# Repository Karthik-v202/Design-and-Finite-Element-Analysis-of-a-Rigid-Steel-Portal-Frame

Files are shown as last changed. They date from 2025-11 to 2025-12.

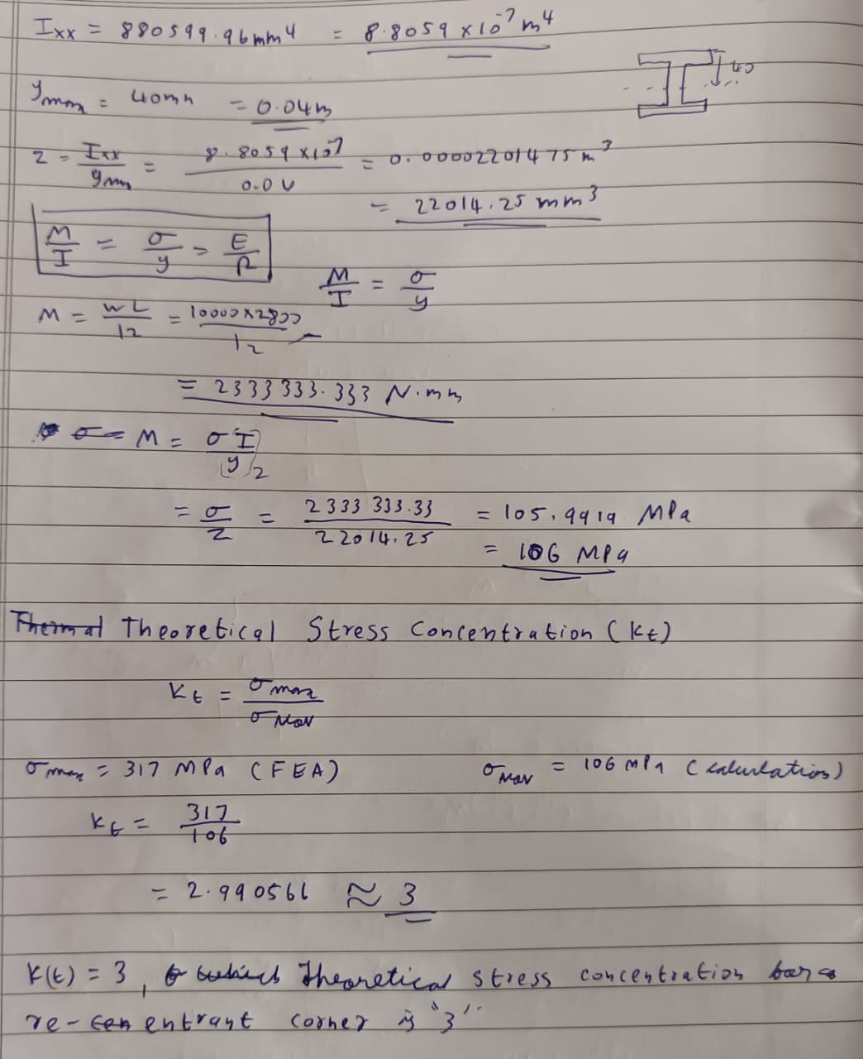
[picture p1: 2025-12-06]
Assets/WhatsApp Image 2025-12-06 at 09.29.01_5a571347.jpg

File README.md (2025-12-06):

# Design and Finite Element Analysis of a Rigid Steel Portal Frame 🏗️

Project Banner
*An industry-standard portal frame designed in SolidWorks, featuring moment-resisting connections and optimized load paths.*

## 🛠️ Tech Stack





## 📖 Project Overview
This project involves the design, failure analysis, and optimization of a structural steel portal frame intended for an industrial warehouse.

Moving beyond basic geometric modeling, this project applies the Six Sigma DMAIC methodology to troubleshoot initial simulation failures (rigid body motion & singularities) and optimize the design to withstand a roof load of $10 \text{ kN}$. The analysis focuses on critical stress concentrations at the eave connections and ensures the structural integrity of the frame through rigorous Finite Element Analysis (FEA).

## ⚙️ Key Design Features (The "Why")

### 1. Haunched Eaves Connection
Haunch Detail
* **Problem:** The connection between the column and rafter experiences the highest **Bending Moment** in the entire structure.
* **Solution:** Designed a tapered haunch to increase the beam depth at the joint. This significantly reduces stress concentration and allows for a lighter rafter section elsewhere.

### 2. Internal Column Stiffeners (Continuity Plates)
Stiffener Detail
* **Problem:** The compression force from the haunch flange pushes directly against the column web, creating a risk of **Local Web Buckling**.
* **Solution:** Modeled horizontal continuity plates inside the column to bridge the load path and transfer forces effectively.

### 3. Detailed Bolted Assemblies
* Utilized standard structural bolts with appropriate pre-tension clusters in the tension zones.
* Designed flush end-plates for manufacturability.

## 🧪 Simulation & Analysis (FEA)
🚩 The Challenge (Define & Measure)

Initial simulations using Beam Elements failed due to connectivity errors (resulting in "flying parts"). Subsequent runs utilizing Solid Elements revealed a peak stress of $475 \text{ MPa}$ at the re-entrant corners. This was identified as a Singularity, which exceeded the yield strength of the initial material (ASTM A36, $S_y=250 \text{ MPa}$).

🛠️ The Fix (Analyze & Improve)

To resolve these issues, the design underwent a rigorous optimization process:

Geometry: Converted all members to Solid Bodies to enable accurate face-to-face bonding and contact set definition.

Refinement: Added Fillet Radii ($5 \text{ mm}$) to simulate weld beads. This smoothed stress flow trajectories and eliminated mathematical singularities caused by sharp corners.

Material Upgrade: Upgraded the material specification from ASTM A36 ($S_y=250 \text{ MPa}$) to ASTM A992 ($S_y=345 \text{ MPa}$) to handle higher allowable stresses.

📸 Final Results (Control)

Stress Final
Stress Almost
Stress Fail

| Metric | Initial Design (Fail) | Optimized Design (Pass) |
| :--- | :--- | :--- |
| **Material** | ASTM A36 ($S_y=250 \text{ MPa}$) | **ASTM A992 (**$S_y=345 \text{ MPa}$**)** |
| **Peak Stress** | $475 \text{ MPa}$ (Singularity) | $317 \text{ MPa}$ **(Safe)** |
| **Deflection** | Infinite (Error) | $5.12 \text{ mm}$ **(Rigid)** |
| **Stability (BLF)** | N/A | $5.05$ **(Extremely Stable)** |

📐 Theoretical Validation

The FEA results were verified against manual Beam Theory calculations to ensure accuracy:

Static Equilibrium: Confirmed $\sum F_y = 0$.

Stress Check: Hand calculations predicted a nominal stress of $106 \text{ MPa}$. The FEA peak of $317 \text{ MPa}$ yields a ratio of $\approx 3.3$. This correlates accurately with the theoretical Stress Concentration Factor ($K_t$) expected for sharp corners and welded joints.

Stiffness Check: The FEA deflection ($5.12 \text{ mm}$) aligns closely with the Fixed-Fixed beam approximation calculation ($3.24 \text{ mm}$), confirming the rigid behavior of the connections.

## 📂 File Structure
- `CAD_Files/`: Native SolidWorks 2024 files.
- `Universal_Formats/`: STEP files for non-SW users.
- `Simulation_Reports/` : Comprehensive report.
- `Drawings/`: 2D Fabrication prints (PDF).

## 👨‍💻 Author
**Karthik V S**
Mechanical Engineering Undergraduate
https://www.linkedin.com/in/karthik-v-s-926b34335

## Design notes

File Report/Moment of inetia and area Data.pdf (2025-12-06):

Measurements are based on sectioned model Section properties of the selected face of steel

Area = 783.24 millimeters^2

Centroid relative to assembly origin: ( millimeters ) X = 0.00
Y = 1995.44
Z = 2204.47

Moments of inertia of the area, at the centroid: ( millimeters ^ 4 )
Lxx = 880599.96 | Lxy = 0.00Lxz = 0.00
Lyx = 0.00 Lyy = 56615.33 | Lyz = 0.01
Lzx = 0.00Lzy = 0.01Lzz = 823984.63

Polar moment of inertia of the area, at the centroid = 880599.96 millimeters ^ 4

Angle between principal axes and assembly coordinate axes = -0.00 degrees

Principal moments of inertia of the area, at the centroid: ( millimeters ^ 4 )
Ix = 56615.33
Iy = 823984.63

Moments of inertia of the area, at the output coordinate system: ( millimeters ^ 4 )
LXX = 6925889576.18 | LXY = 0.00 | LXZ = 0.00
LYX = 0.00 LYY = 3806356861.54LYZ = 3445394289.02
LZX = 0.00 | LZY = 3445394289.02 | LZZ = 3119532714.64

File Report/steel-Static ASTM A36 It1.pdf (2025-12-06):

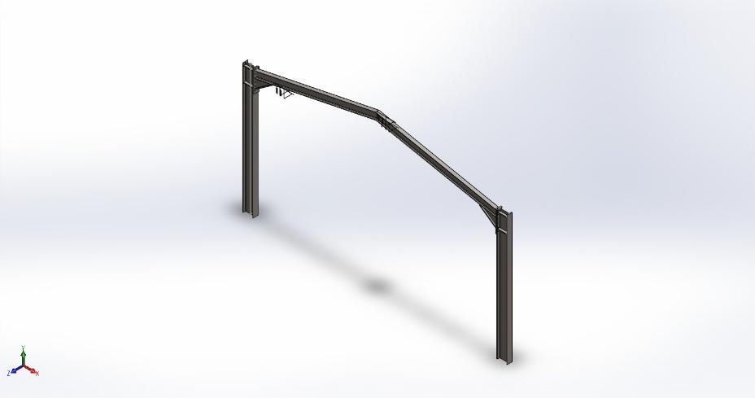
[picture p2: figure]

Analyzed with SOLIDWORKS Simulation | Simulation of steel | 1

# Simulation of steel

Date: 01 December 2025
Designer: Solidworks
Study name: Static 1
Analysis type: Static

## Table of Contents

## Description

No Data

## Assumptions

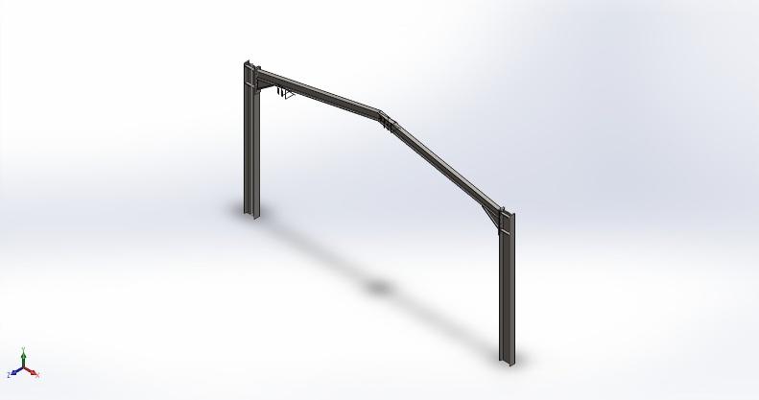
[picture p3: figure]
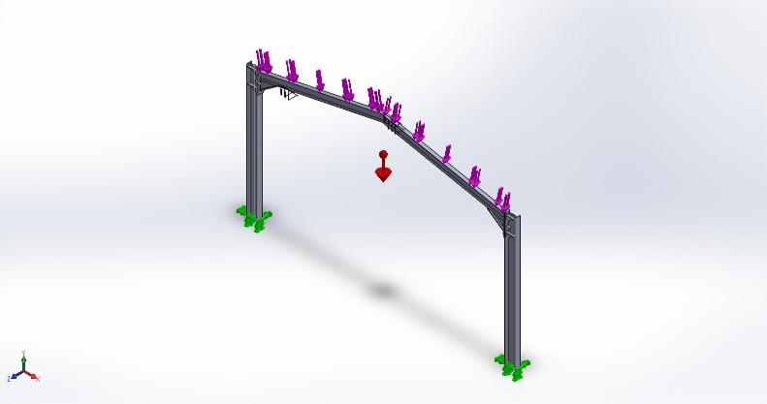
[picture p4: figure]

Original Model | Model Analyzed

## Model Information

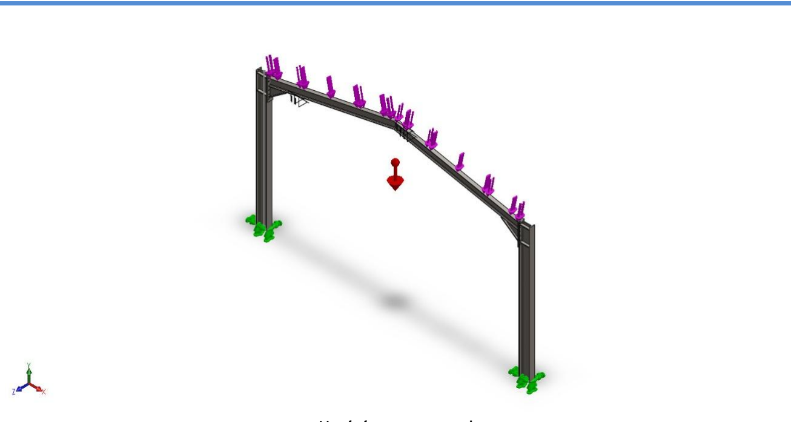
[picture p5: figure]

Model name: steel
Current Configuration: Default

### Solid Bodies

Document Name and Reference | Treated As | Volumetric Properties | Document Path/Date Modified
Trim/Extend1[1] | Solid Body | Mass:8.65652 kg Volume:0.00110274 m^3 Density:7,850 kg/m^3 Weight:84.8339 N | C:\Users\HP\Desktop\CAD _Files\Steel 1.SLDPRT Dec 1 16:14:57 2025
Mirror2[1] | Solid Body | Mass:0.615448 kg Volume:7.8401e-05 m^3 Density:7,850 kg/m^3 Weight:6.03139 N | C:\Users\HP\Desktop\CAD _Files\Steel 1.SLDPRT Dec 1 16:14:57 2025

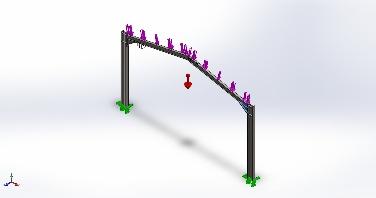
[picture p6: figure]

Cut-Extrude3[1] | Solid Body | Mass:17.1355 kg Volume:0.00218286 m^3 Density:7,850 kg/m^3 Weight:167.928 N | C:\Users\HP\Desktop\CAD _Files\Steel 1.SLDPRT Dec 1 16:14:57 2025

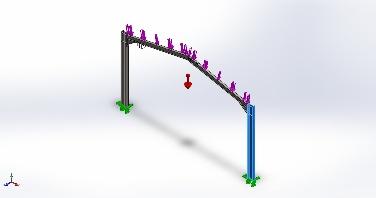
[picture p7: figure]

Gusset1 | Solid Body | Mass:0.615448 kg Volume:7.8401e-05 m^3 Density:7,850 kg/m^3 Weight:6.03139 N | C:\Users\HP\Desktop\CAD _Files\Steel 1.SLDPRT Dec 1 16:14:57 2025

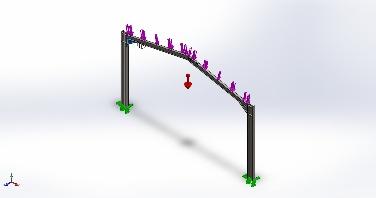
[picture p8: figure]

Trim/Extend1[2] | Solid Body | Mass:8.65652 kg Volume:0.00110274 m^3 Density:7,850 kg/m^3 Weight:84.8339 N | C:\Users\HP\Desktop\CAD _Files\Steel 1.SLDPRT Dec 1 16:14:57 2025
Cut-Extrude2[1] | Solid Body | Mass:17.1584 kg Volume:0.00218578 m^3 Density:7,850 kg/m^3 Weight:168.152 N | C:\Users\HP\Desktop\CAD _Files\Steel 1.SLDPRT Dec 1 16:14:57 2025

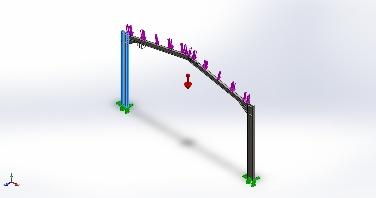
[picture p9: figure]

## Study Properties

Study name | Static 1
Analysis type | Static
Mesh type | Mixed Mesh
Thermal Effect: | On
Thermal option | Include temperature loads
Zero strain temperature | 298 Kelvin
Include fluid pressure effects from SOLIDWORKS Flow Simulation | Off
Solver type | Automatic
Inplane Effect: | Off
Soft Spring: | Off
Inertial Relief: | Off
Incompatible bonding options | Automatic
Large displacement | Off
Compute free body forces | On
Friction | Off
Use Adaptive Method: | Off
Result folder | SOLIDWORKS document (C:\Users\HP\Desktop\CAD_Files)

## Units

Unit system: | SI (MKS)
Length/Displacement | mm
Temperature | Kelvin
Angular velocity | Rad/sec
Pressure/Stress | N/m^2

## Material Properties

Model Reference | Properties | Components
| Name: ASTM A36 Steel Model type: Linear Elastic Isotropic Default failure criterion: Max von Mises Stress
| Yield strength: 2.5e+08 N/m^2 Tensile strength: 4e+08 N/m^2 Elastic modulus: 2e+11 N/m^2 Poisson's ratio: 0.26 Mass density: 7,850 kg/m^3 Shear modulus: 7.93e+10 N/m^2

SolidBody 1(Base-Flange14)(Steel 1-2),
SolidBody 2(Base-Flange2)(Steel 1-2),
SolidBody 3(Base-Flange9)(Steel 1-2),
SolidBody 4(Base-Flange13)(Steel 1-2),
SolidBody
5(Trim/Extend1[1])(Steel 1-2),
SolidBody 6(Cut-Extrude2[2])(Steel 1-2),
SolidBody 7(Base-Flange4)(Steel 1-2),
SolidBody 8(Base-Flange8)(Steel 1-2),
SolidBody 9(Base-Flange12)(Steel 1-2),
SolidBody
10(Mirror2[1])(Steel 1-2), SolidBody 11(Cut-Extrude3[1])(Steel 1-2),
SolidBody 12(Base-Flange7)(Steel 1-2),
SolidBody 13(Base-Flange11)(Steel 1-2),
SolidBody 14(Gusset1)(Steel 1-2),
SolidBody
15(Trim/Extend1[2])(Steel 1-2),
SolidBody 16(Cut-Extrude2[1])(Steel 1-2),
SolidBody 17(Cut-Extrude3[2])(Steel 1-2),
SolidBody 18(Base-Flange10)(Steel 1-2)

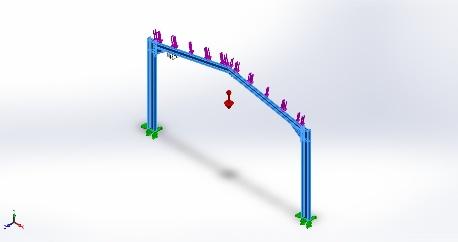
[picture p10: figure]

Curve Data:N/A

## Loads and Fixtures

Fixture name | Fixture Image | Fixture Details

Fixed-1

Entities: 2 face(s)
Type: Fixed
Geometry

Resultant Forces

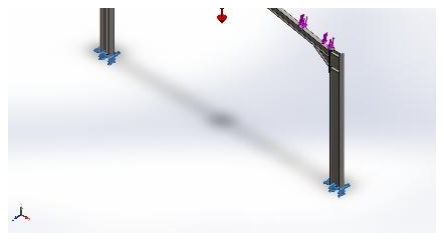
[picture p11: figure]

Components | X | Y | Z | Resultant
Reaction force(N) | -0.0880032 | 20,168.1 | 0.140892 | 20,168.1
Reaction Moment(N.m) | 0 | 0 | 0 | 1e-33
Load name | Load Image | Load Details

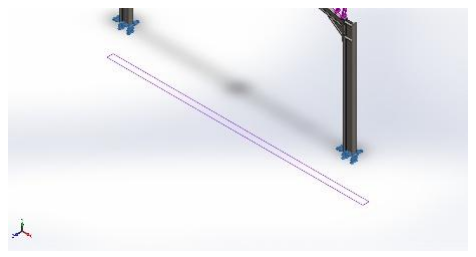
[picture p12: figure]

Gravity-1

Reference: Top Plane
Values: 0 0 -9.81
Units: m/s^2

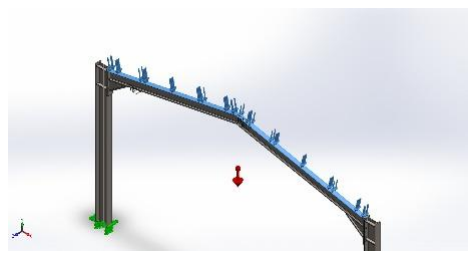
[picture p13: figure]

Force-1

Entities: 2 face(s)
Type: Apply
normal
force
Value: 10,000 N

## Connector Definitions

No Data

## Interaction Information

Interaction | Interaction Image | Interaction Properties

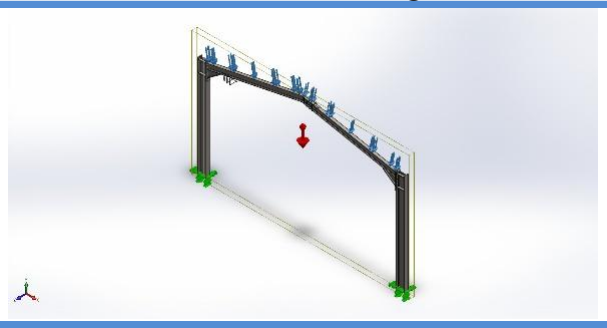
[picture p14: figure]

Global Interaction | | Type: Bonded Components: 1 component(s) Options: Independent mesh

## Mesh information

Mesh type | Mixed Mesh
Mesher Used: | Blended curvature-based mesh
Jacobian points for High quality mesh | 16 Points
Jacobian check for shell | On
Maximum element size | 30.3492 mm
Minimum element size | 1.51746 mm
Mesh Quality | High
Remesh failed parts independently | Off
Reuse mesh for identical parts in an assembly (Blended curvature-based mesher only) | Off

### Mesh information - Details

Total Nodes | 682917
Total Elements | 374468
Time to complete mesh(hh;mm;ss): | 00:00:31

Computer name:

### Mesh Quality Plots

Name | Type | Min | Max
Quality1 | Mesh | - | -

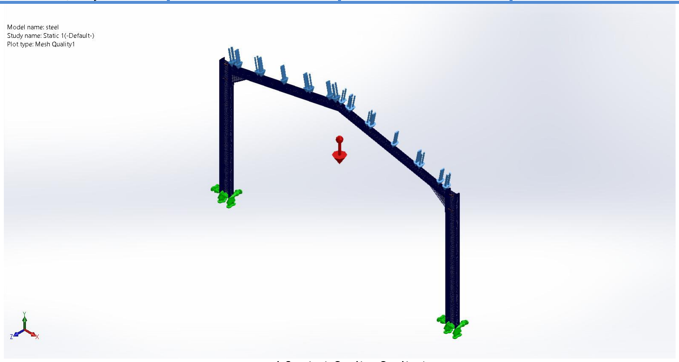
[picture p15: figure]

steel-Static 1-Quality-Quality1

## Sensor Details

No Data

## Resultant Forces

### Reaction forces

Selection set | Units | Sum X | Sum Y | Sum Z | Resultant
Entire Model | N | -0.0880032 | 20,168.1 | 0.140892 | 20,168.1

### Reaction Moments

Selection set | Units | Sum X | Sum Y | Sum Z | Resultant
Entire Model | N.m | 0 | 0 | 0 | 1e-33

### Free body forces

Selection set | Units | Sum X | Sum Y | Sum Z | Resultant
Entire Model | N | -5.40119 | 402.134 | -33.7607 | 403.585

### Free body moments

Selection set | Units | Sum X | Sum Y | Sum Z | Resultant
Entire Model | N.m | -0.307049 | -0.0124856 | 0.213525 | 0.374203

## Beams

### No Data

## Study Results

Name | Type | Min | Max
Stress1 | VON: von Mises Stress | 1.079e+04N/m^2 Node: 302349 | 4.749e+08N/m^2 Node: 526510

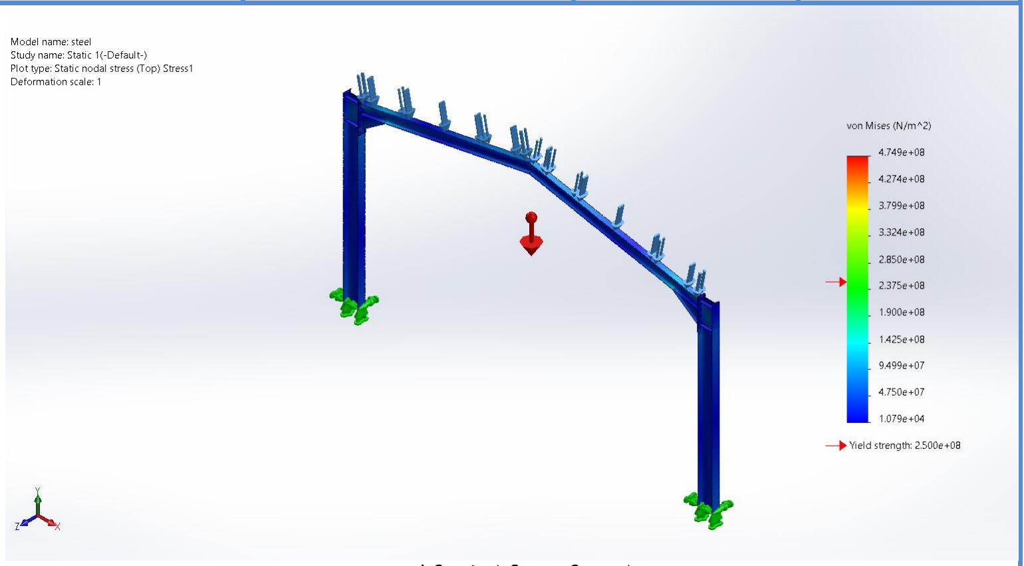
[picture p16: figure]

steel-Static 1-Stress-Stress1

Name | Type | Min | Max
Displacement1 | URES: Resultant Displacement | 0.000e+00mm Node: 191339 | 5.124e+00mm Node: 6452

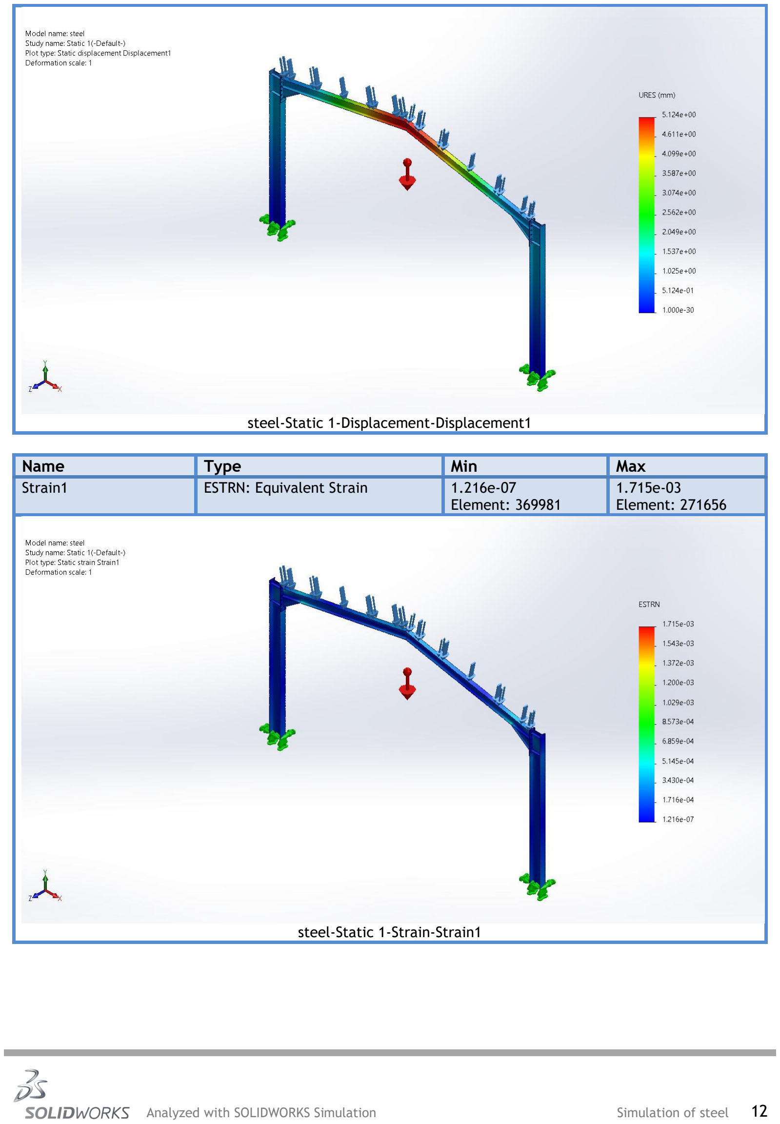
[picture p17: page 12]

steel-Static 1-Displacement-Displacement1

Name | Type | Min | Max
Strain1 | ESTRN: Equivalent Strain | 1.216e-07 Element: 369981 | 1.715e-03 Element: 271656

steel-Static 1-Strain-Strain1

## Conclusion

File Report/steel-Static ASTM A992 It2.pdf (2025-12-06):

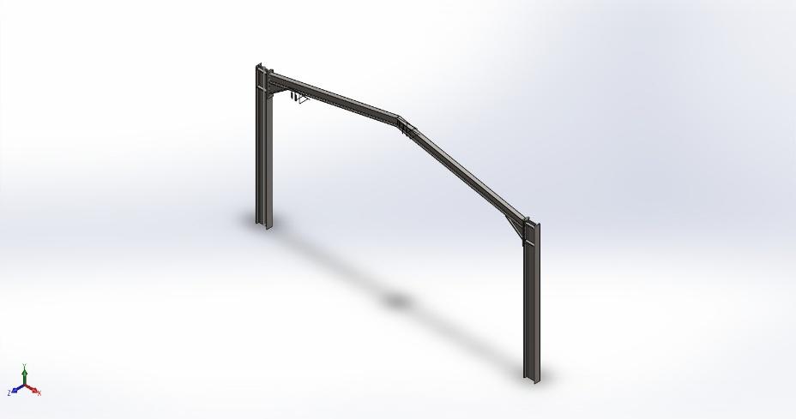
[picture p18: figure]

Analyzed with SOLIDWORKS Simulation | Simulation of steel | 1

# Simulation of steel

Date: 01 December 2025
Designer: Solidworks
Study name: Static 2
Analysis type: Static

## Table of Contents

## Description

No Data

## Assumptions

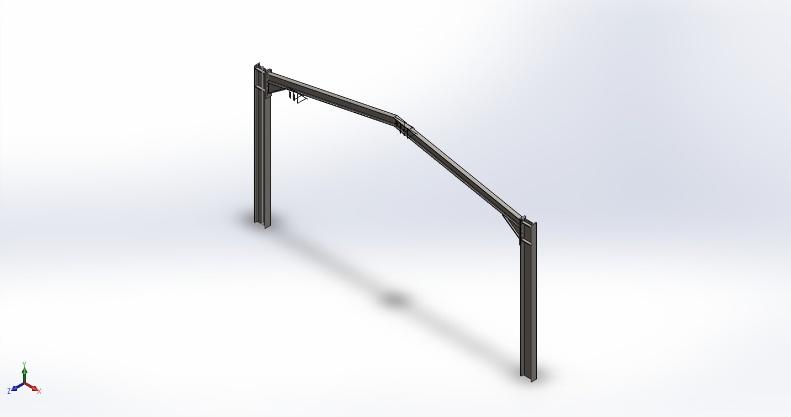
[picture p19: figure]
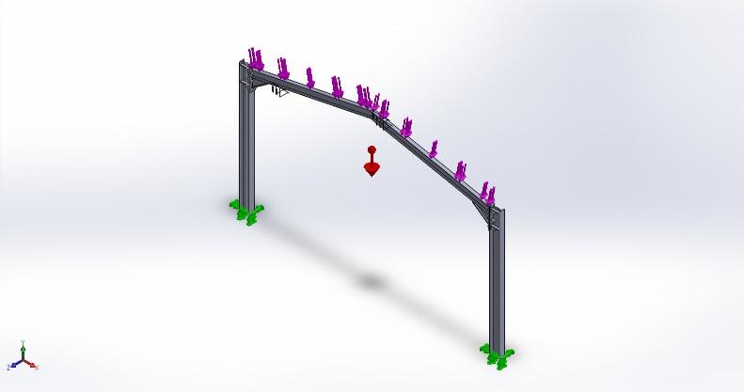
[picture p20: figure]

Original Model | Model Analyzed

## Model Information


Model name: steel
Current Configuration: Default

### Solid Bodies

Document Name and Reference | Treated As | Volumetric Properties | Document Path/Date Modified
Trim/Extend1[2] | Solid Body | Mass:8.65652 kg Volume:0.00110274 m^3 Density:7,850 kg/m^3 Weight:84.8339 N | C:\Users\HP\Desktop\CAD _Files\Steel 1.SLDPRT Dec 1 16:14:57 2025
Mirror2[1] | Solid Body | Mass:0.615448 kg Volume:7.8401e-05 m^3 Density:7,850 kg/m^3 Weight:6.03139 N | C:\Users\HP\Desktop\CAD _Files\Steel 1.SLDPRT Dec 1 16:14:57 2025


Cut-Extrude3[1] | Solid Body | Mass:17.1355 kg Volume:0.00218286 m^3 Density:7,850 kg/m^3 Weight:167.928 N | C:\Users\HP\Desktop\CAD _Files\Steel 1.SLDPRT Dec 1 16:14:57 2025


Gusset1 | Solid Body | Mass:0.615448 kg Volume:7.8401e-05 m^3 Density:7,850 kg/m^3 Weight:6.03139 N | C:\Users\HP\Desktop\CAD _Files\Steel 1.SLDPRT Dec 1 16:14:57 2025


Trim/Extend1[1] | Solid Body | Mass:8.65652 kg Volume:0.00110274 m^3 Density:7,850 kg/m^3 Weight:84.8339 N | C:\Users\HP\Desktop\CAD _Files\Steel 1.SLDPRT Dec 1 16:14:57 2025
Cut-Extrude2[1] | Solid Body | Mass:17.1584 kg Volume:0.00218578 m^3 Density:7,850 kg/m^3 Weight:168.152 N | C:\Users\HP\Desktop\CAD _Files\Steel 1.SLDPRT Dec 1 16:14:57 2025


## Study Properties

Study name | Static 2
Analysis type | Static
Mesh type | Mixed Mesh
Thermal Effect: | On
Thermal option | Include temperature loads
Zero strain temperature | 298 Kelvin
Include fluid pressure effects from SOLIDWORKS Flow Simulation | Off
Solver type | Automatic
Inplane Effect: | Off
Soft Spring: | Off
Inertial Relief: | Off
Incompatible bonding options | Automatic
Large displacement | Off
Compute free body forces | On
Friction | Off
Use Adaptive Method: | Off
Result folder | SOLIDWORKS document (C:\Users\HP\Desktop\CAD_Files)

## Units

Unit system: | SI (MKS)
Length/Displacement | mm
Temperature | Kelvin
Angular velocity | Rad/sec
Pressure/Stress | N/m^2

## Material Properties

Model Reference | Properties | Components
| Name: ASTM A992 Model type: Linear Elastic Isotropic Default failure criterion: Max von Mises Stress
| Yield strength: 3.45e+08 N/m^2 Tensile strength: 4e+08 N/m^2 Elastic modulus: 2e+11 N/m^2 Poisson's ratio: 0.26 Mass density: 7,850 kg/m^3 Shear modulus: 7.93e+10 N/m^2

SolidBody
1(Trim/Extend1[2])(Steel 1-2),
SolidBody 2(Mirror2[1])(Steel 1-2),
SolidBody 3(Cut-Extrude3[2])(Steel 1-2),
SolidBody 4(Cut-Extrude3[1])(Steel 1-2),
SolidBody 5(Base-Flange13)(Steel 1-2),
SolidBody 6(Base-Flange11)(Steel 1-2),
SolidBody 7(Base-Flange9)(Steel 1-2),
SolidBody 8(Base-Flange7)(Steel 1-2),
SolidBody 9(Gusset1)(Steel 1-2),
SolidBody
10(Trim/Extend1[1])(Steel 1-2),
SolidBody 11(Cut-Extrude2[2])(Steel 1-2),
SolidBody 12(Base-Flange12)(Steel 1-2),
SolidBody 13(Base-Flange2)(Steel 1-2),
SolidBody 14(Cut-Extrude2[1])(Steel 1-2),
SolidBody 15(Base-Flange10)(Steel 1-2),
SolidBody 16(Base-Flange4)(Steel 1-2),
SolidBody 17(Base-Flange8)(Steel 1-2),
SolidBody 18(Base-Flange14)(Steel 1-2)

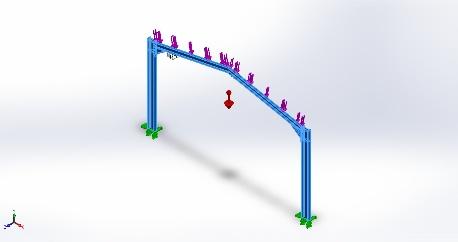
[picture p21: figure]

Curve Data:N/A

## Loads and Fixtures

Fixture name | Fixture Image | Fixture Details

Fixed-1

Entities: 2 face(s)
Type: Fixed
Geometry

Resultant Forces


Components | X | Y | Z | Resultant
Reaction force(N) | -0.122177 | 20,167.2 | -0.103241 | 20,167.2
Reaction Moment(N.m) | 0 | 0 | 0 | 1e-33
Load name | Load Image | Load Details


Gravity-1

Reference: Top Plane
Values: 0 0 -9.81
Units: m/s^2

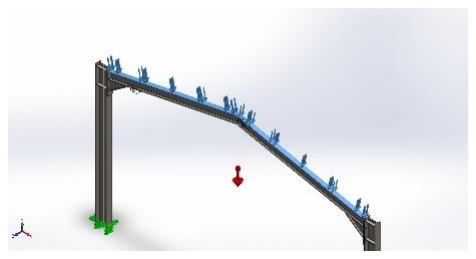
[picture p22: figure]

Force-1

Entities: 2 face(s)
Type: Apply
normal
force
Value: 10,000 N

## Connector Definitions

No Data

## Interaction Information

Interaction | Interaction Image | Interaction Properties


Global Interaction | | Type: Bonded Components: 1 component(s) Options: Independent mesh

## Mesh information

Mesh type | Mixed Mesh
Mesher Used: | Blended curvature-based mesh
Jacobian points for High quality mesh | 16 Points
Jacobian check for shell | On
Maximum element size | 30.3492 mm
Minimum element size | 1.51746 mm
Mesh Quality | High
Remesh failed parts independently | Off
Reuse mesh for identical parts in an assembly (Blended curvature-based mesher only) | Off

### Mesh information - Details

Total Nodes | 682917
Total Elements | 374468
Time to complete mesh(hh;mm;ss): | 00:00:54

Computer name:

### Mesh Quality Plots

Name | Type | Min | Max
Quality1 | Mesh | - | -

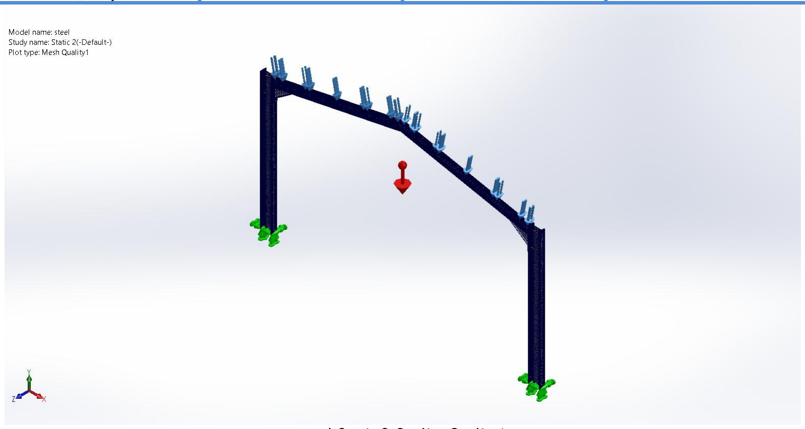
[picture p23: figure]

steel-Static 2-Quality-Quality1

## Sensor Details

No Data

## Resultant Forces

### Reaction forces

Selection set | Units | Sum X | Sum Y | Sum Z | Resultant
Entire Model | N | -0.122177 | 20,167.2 | -0.103241 | 20,167.2

### Reaction Moments

Selection set | Units | Sum X | Sum Y | Sum Z | Resultant
Entire Model | N.m | 0 | 0 | 0 | 1e-33

### Free body forces

Selection set | Units | Sum X | Sum Y | Sum Z | Resultant
Entire Model | N | -6.93514 | 387.366 | 48.4837 | 390.45

### Free body moments

Selection set | Units | Sum X | Sum Y | Sum Z | Resultant
Entire Model | N.m | -0.332162 | -0.0124793 | 0.190236 | 0.382985

## Beams

### No Data

## Study Results

Name | Type | Min | Max
Stress1 | VON: von Mises Stress | 1.208e+04N/m^2 Node: 530277 | 4.749e+08N/m^2 Node: 187743

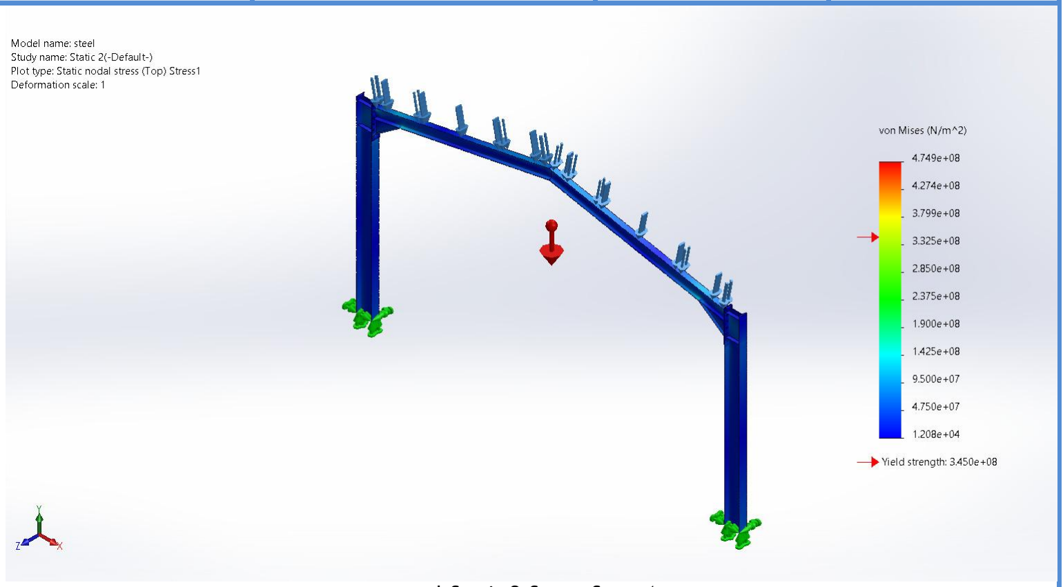
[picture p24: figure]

steel-Static 2-Stress-Stress1

Name | Type | Min | Max
Displacement1 | URES: Resultant Displacement | 0.000e+00mm Node: 191708 | 5.124e+00mm Node: 6460

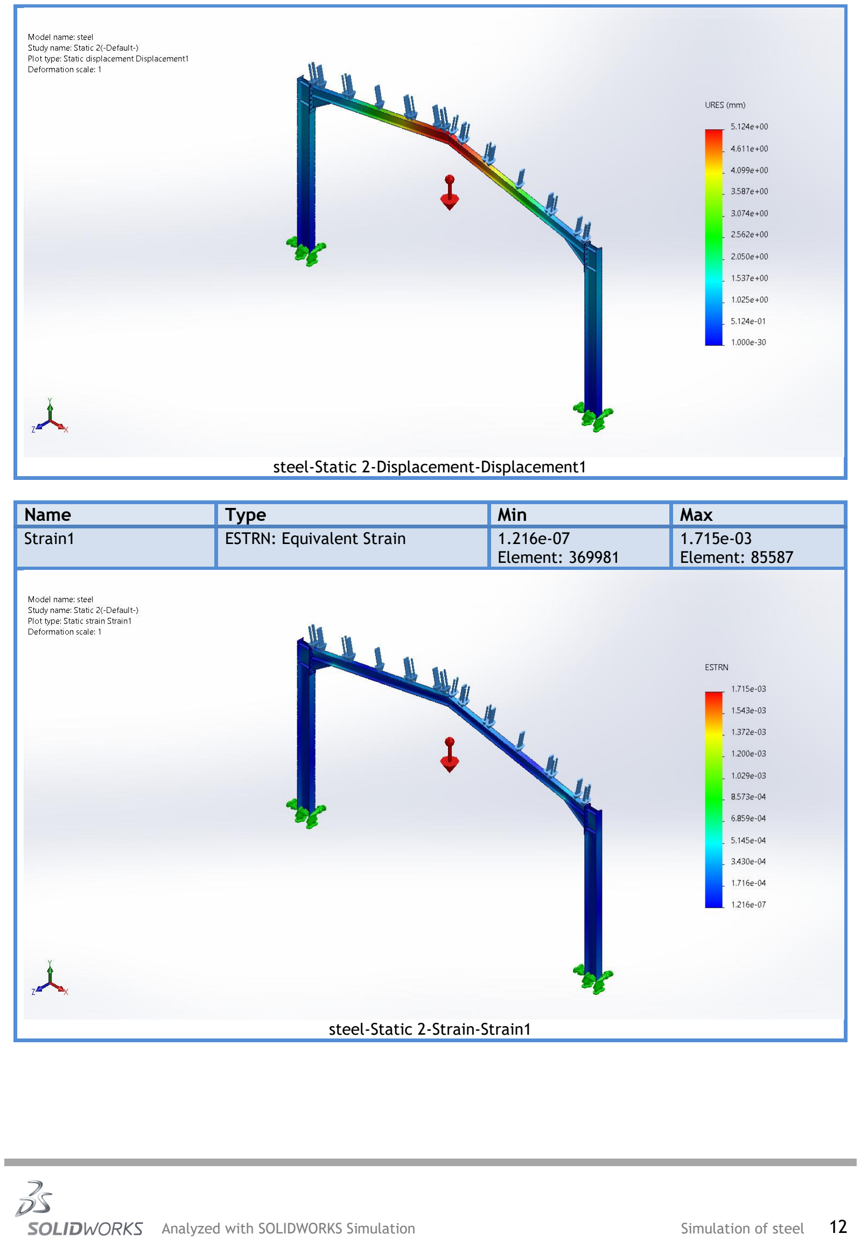
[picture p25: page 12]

steel-Static 2-Displacement-Displacement1

Name | Type | Min | Max
Strain1 | ESTRN: Equivalent Strain | 1.216e-07 Element: 369981 | 1.715e-03 Element: 85587

steel-Static 2-Strain-Strain1

## Conclusion

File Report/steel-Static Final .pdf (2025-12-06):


Analyzed with SOLIDWORKS Simulation | Simulation of steel | 1

# Simulation of steel

Date: 05 December 2025
Designer: Karthik V S
Study name: Static 1
Analysis type: Static

## Table of Contents

## Description

No Data

Karthik V S
05-12-2025

## Assumptions


Original Model | Model Analyzed

## Model Information


Model name: steel
Current Configuration: Default

### Solid Bodies

Document Name and Reference | Treated As | Volumetric Properties | Document Path/Date Modified
Fillet Bead15 | Solid Body | Mass:0.0286001 kg Volume:3.64333e-06 m^3 Density:7,850 kg/m^3 Weight:0.280281 N | C:\Users\HP\Desktop\Test cad\Steel 1.SLDPRT Dec 1 22:43:37 2025


Base-Flange10 | Solid Body | Mass:0.156986 kg Volume:1.99983e-05 m^3 Density:7,850 kg/m^3 Weight:1.53847 N | C:\Users\HP\Desktop\Test cad\Steel 1.SLDPRT Dec 1 22:43:37 2025
Fillet Bead24 | Solid Body | Mass:0.0231394 kg Volume:2.94769e-06 m^3 Density:7,850 kg/m^3 Weight:0.226766 N | C:\Users\HP\Desktop\Test cad\Steel 1.SLDPRT Dec 1 22:43:37 2025


Base-Flange7 | Solid Body | Mass:0.156986 kg Volume:1.99983e-05 m^3 Density:7,850 kg/m^3 Weight:1.53847 N | C:\Users\HP\Desktop\Test cad\Steel 1.SLDPRT Dec 1 22:43:37 2025


Fillet Bead22 | Solid Body | Mass:0.0286001 kg Volume:3.64333e-06 m^3 Density:7,850 kg/m^3 | C:\Users\HP\Desktop\Test cad\Steel 1.SLDPRT Dec 1 22:43:37 2025

Weight:0.280281 N

Fillet18 | Solid Body | Mass:9.90897 kg Volume:0.00126229 m^3 Density:7,850 kg/m^3 Weight:97.1079 N | C:\Users\HP\Desktop\Test cad\Steel 1.SLDPRT Dec 1 22:43:37 2025


Base-Flange11 | Solid Body | Mass:0.156986 kg Volume:1.99983e-05 m^3 Density:7,850 kg/m^3 Weight:1.53847 N | C:\Users\HP\Desktop\Test cad\Steel 1.SLDPRT Dec 1 22:43:37 2025


Cut-Extrude2[1] | Solid Body | Mass:17.1584 kg Volume:0.00218578 m^3 Density:7,850 kg/m^3 Weight:168.152 N | C:\Users\HP\Desktop\Test cad\Steel 1.SLDPRT Dec 1 22:43:37 2025


Cut-Extrude3[1] | Solid Body | Mass:17.1355 kg Volume:0.00218286 m^3 Density:7,850 kg/m^3 Weight:167.928 N | C:\Users\HP\Desktop\Test cad\Steel 1.SLDPRT Dec 1 22:43:37 2025
Base-Flange8 | Solid Body | Mass:0.156986 kg Volume:1.99983e-05 m^3 Density:7,850 kg/m^3 Weight:1.53847 N | C:\Users\HP\Desktop\Test cad\Steel 1.SLDPRT Dec 1 22:43:37 2025


Base-Flange14 | Solid Body | Mass:0.156986 kg Volume:1.99983e-05 m^3 Density:7,850 kg/m^3 Weight:1.53847 N | C:\Users\HP\Desktop\Test cad\Steel 1.SLDPRT Dec 1 22:43:37 2025


Fillet Bead10 | Solid Body | Mass:0.0286001 kg Volume:3.64333e-06 m^3 Density:7,850 kg/m^3 Weight:0.280281 N | C:\Users\HP\Desktop\Test cad\Steel 1.SLDPRT Dec 1 22:43:37 2025
Fillet Bead17 | Solid Body | Mass:0.0231394 kg Volume:2.94769e-06 m^3 | C:\Users\HP\Desktop\Test cad\Steel 1.SLDPRT

Density:7,850 kg/m^3 Weight:0.226766 N | Dec 1 22:43:37 2025


Gusset1 | Solid Body | Mass:0.615448 kg Volume:7.8401e-05 m^3 Density:7,850 kg/m^3 Weight:6.03139 N | C:\Users\HP\Desktop\Test cad\Steel 1.SLDPRT Dec 1 22:43:37 2025


Mirror2[1] | Solid Body | Mass:0.615448 kg Volume:7.8401e-05 m^3 Density:7,850 kg/m^3 Weight:6.03139 N | C:\Users\HP\Desktop\Test cad\Steel 1.SLDPRT Dec 1 22:43:37 2025


Fillet Bead16 | Solid Body | Mass:0.0231394 kg Volume:2.94769e-06 m^3 Density:7,850 kg/m^3 Weight:0.226766 N | C:\Users\HP\Desktop\Test cad\Steel 1.SLDPRT Dec 1 22:43:37 2025
Base-Flange12 | Solid Body | Mass:0.156986 kg Volume:1.99983e-05 m^3 Density:7,850 kg/m^3 Weight:1.53847 N | C:\Users\HP\Desktop\Test cad\Steel 1.SLDPRT Dec 1 22:43:37 2025


Base-Flange2 | Solid Body | Mass:0.604748 kg Volume:7.7038e-05 m^3 Density:7,850 kg/m^3 Weight:5.92653 N | C:\Users\HP\Desktop\Test cad\Steel 1.SLDPRT Dec 1 22:43:37 2025


Base-Flange9 | Solid Body | Mass:0.156986 kg Volume:1.99983e-05 m^3 Density:7,850 kg/m^3 Weight:1.53847 N | C:\Users\HP\Desktop\Test cad\Steel 1.SLDPRT Dec 1 22:43:37 2025


Fillet13 | Solid Body | Mass:9.9117 kg Volume:0.00126264 m^3 Density:7,850 kg/m^3 Weight:97.1347 N | C:\Users\HP\Desktop\Test cad\Steel 1.SLDPRT Dec 1 22:43:37 2025
Base-Flange4 | Solid Body | Mass:0.604748 kg Volume:7.7038e-05 m^3 | C:\Users\HP\Desktop\Test cad\Steel 1.SLDPRT

Density:7,850 kg/m^3 Weight:5.92653 N | Dec 1 22:43:37 2025


Base-Flange13 | Solid Body | Mass:0.156986 kg Volume:1.99983e-05 m^3 Density:7,850 kg/m^3 Weight:1.53847 N | C:\Users\HP\Desktop\Test cad\Steel 1.SLDPRT Dec 1 22:43:37 2025


Fillet Bead18 | Solid Body | Mass:0.0286001 kg Volume:3.64333e-06 m^3 Density:7,850 kg/m^3 Weight:0.280281 N | C:\Users\HP\Desktop\Test cad\Steel 1.SLDPRT Dec 1 22:43:37 2025

## Study Properties

Study name | Static 1
Analysis type | Static
Mesh type | Solid Mesh
Thermal Effect: | On
Thermal option | Include temperature loads
Zero strain temperature | 298 Kelvin
Include fluid pressure effects from SOLIDWORKS Flow Simulation | Off
Solver type | Automatic
Inplane Effect: | Off
Soft Spring: | Off
Inertial Relief: | Off
Incompatible bonding options | Automatic
Large displacement | Off
Compute free body forces | On
Friction | Off
Use Adaptive Method: | Off
Result folder | SOLIDWORKS document (C:\Users\HP\Desktop\Test cad)

## Units

Unit system: | SI (MKS)
Length/Displacement | mm
Temperature | Kelvin
Angular velocity | Rad/sec
Pressure/Stress | N/m^2

## Material Properties

Model Reference | Properties | Components
| Name: ASTM A992 Model type: Linear Elastic Isotropic Default failure criterion: Max von Mises Stress
| Yield strength: 3.45e+08 N/m^2 Tensile strength: 4e+08 N/m^2 Elastic modulus: 2e+11 N/m^2 Poisson's ratio: 0.26 Mass density: 7,850 kg/m^3 Shear modulus: 7.93e+10 N/m^2

SolidBody 1(Fillet
Bead15)(Steel 1-2),
SolidBody 2(Base-Flange10)(Steel 1-2),
SolidBody 3(Fillet
Bead24)(Steel 1-2),
SolidBody 4(Base-Flange7)(Steel 1-2),
SolidBody 5(Fillet
Bead22)(Steel 1-2),
SolidBody 6(Fillet18)(Steel 1-2),
SolidBody 7(Base-Flange11)(Steel 1-2),
SolidBody 8(Cut-Extrude2[1])(Steel 1-2),
SolidBody 9(Cut-Extrude3[1])(Steel 1-2),
SolidBody 10(Base-Flange8)(Steel 1-2),
SolidBody 11(Base-Flange14)(Steel 1-2),
SolidBody 12(Fillet
Bead10)(Steel 1-2),
SolidBody 13(Fillet
Bead17)(Steel 1-2),
SolidBody 14(Gusset1)(Steel 1-2),
SolidBody
15(Mirror2[1])(Steel 1-2), SolidBody 16(Fillet
Bead16)(Steel 1-2),
SolidBody 17(Base-Flange12)(Steel 1-2),
SolidBody 18(Base-Flange2)(Steel 1-2),
SolidBody 19(Base-Flange9)(Steel 1-2),
SolidBody 20(Fillet13)(Steel 1-2),
SolidBody 21(Base-Flange4)(Steel 1-2),
SolidBody 22(Base-Flange13)(Steel 1-2),
SolidBody 23(Fillet
Bead18)(Steel 1-2)

Curve Data:N/A

## Loads and Fixtures

Fixture name | Fixture Image | Fixture Details

Fixed-1

Entities: 2 face(s)
Type: Fixed
Geometry

Resultant Forces


Components | X | Y | Z | Resultant
Reaction force(N) | 0.129459 | 20,168.7 | -0.447311 | 20,168.7
Reaction Moment(N.m) | 0 | 0 | 0 | 0
Load name | Load Image | Load Details

Gravity-1

Reference: Top Plane
Values: 0 0 -9.81
Units: m/s^2

Force-1

Entities: 2 face(s)
Type: Apply
normal
force
Value: 10,000 N

## Connector Definitions

No Data

## Interaction Information

Interaction | Interaction Image | Interaction Properties
Global Interaction | | Type: Bonded Components: 1 component(s) Options: Independent mesh

## Mesh information

Mesh type | Solid Mesh
Mesher Used: | Blended curvature-based mesh
Jacobian points for High quality mesh | 16 Points
Maximum element size | 31.1061 mm
Minimum element size | 1.5553 mm
Mesh Quality | High
Remesh failed parts independently | Off
Reuse mesh for identical parts in an assembly (Blended curvature-based mesher only) | Off

### Mesh information - Details

Total Nodes | 705930
Total Elements | 388199
Maximum Aspect Ratio | 36.916
% of elements with Aspect Ratio < 3 | 98.1
Percentage of elements with Aspect Ratio > 10 | 0.00206
Percentage of distorted elements | 0
Time to complete mesh(hh;mm;ss): | 00:00:18

Computer name:

### Mesh Quality Plots

Name | Type | Min | Max
Quality1 | Mesh | - | -


steel-Static 1-Quality-Quality1

## Sensor Details

No Data

## Resultant Forces

### Reaction forces

Selection set | Units | Sum X | Sum Y | Sum Z | Resultant
Entire Model | N | 0.129459 | 20,168.7 | -0.447311 | 20,168.7

### Reaction Moments

Selection set | Units | Sum X | Sum Y | Sum Z | Resultant
Entire Model | N.m | 0 | 0 | 0 | 0

### Free body forces

Selection set | Units | Sum X | Sum Y | Sum Z | Resultant
Entire Model | N | 9.33306 | 422.145 | 18.9509 | 422.673

### Free body moments

Selection set | Units | Sum X | Sum Y | Sum Z | Resultant
Entire Model | N.m | 0 | 0 | 0 | 1e-33

## Beams

### No Data

## Study Results

Name | Type | Min | Max
Stress1 | VON: von Mises Stress | 1.436e+04N/m^2 Node: 395964 | 3.174e+08N/m^2 Node: 699800


steel-Static 1-Stress-Stress1

Name | Type | Min | Max
Displacement1 | URES: Resultant Displacement | 0.000e+00mm Node: 197260 | 5.117e+00mm Node: 2165


steel-Static 1-Displacement-Displacement1

Name | Type | Min | Max
Strain1 | ESTRN: Equivalent Strain | 1.553e-07 Element: 197499 | 1.157e-03 Element: 2776

steel-Static 1-Strain-Strain1

Image-1

Image-2


Image-3

## Conclusion

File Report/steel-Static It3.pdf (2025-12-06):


Analyzed with SOLIDWORKS Simulation | Simulation of steel | 1

# Simulation of steel

Date: 05 December 2025
Designer: Solidworks
Study name: Static 1
Analysis type: Static

## Table of Contents

## Description

No Data

## Assumptions


Original Model | Model Analyzed

## Model Information


Model name: steel
Current Configuration: Default

### Solid Bodies

Document Name and Reference | Treated As | Volumetric Properties | Document Path/Date Modified
Cut-Extrude2[1] | Solid Body | Mass:17.1584 kg Volume:0.00218578 m^3 Density:7,850 kg/m^3 Weight:168.152 N | C:\Users\HP\Desktop\Stee l 1.SLDPRT Dec 4 08:17:11 2025


Boss-Extrude6 | Solid Body | Mass:0.437691 kg Volume:5.57569e-05 m^3 Density:7,850 kg/m^3 Weight:4.28938 N | C:\Users\HP\Desktop\Stee l 1.SLDPRT Dec 4 08:17:11 2025


Boss-Extrude1 | Solid Body | Mass:0.437691 kg Volume:5.57569e-05 m^3 Density:7,850 kg/m^3 Weight:4.28938 N | C:\Users\HP\Desktop\Stee l 1.SLDPRT Dec 4 08:17:11 2025


Trim/Extend1[1] | Solid Body | Mass:8.65652 kg Volume:0.00110274 m^3 Density:7,850 kg/m^3 Weight:84.8339 N | C:\Users\HP\Desktop\Stee l 1.SLDPRT Dec 4 08:17:11 2025
Boss-Extrude3 | Solid Body | Mass:0.437691 kg Volume:5.57569e-05 m^3 Density:7,850 kg/m^3 Weight:4.28938 N | C:\Users\HP\Desktop\Steel 1.SLDPRT Dec 4 08:17:11 2025


Boss-Extrude5 | Solid Body | Mass:0.437691 kg Volume:5.57569e-05 m^3 Density:7,850 kg/m^3 | C:\Users\HP\Desktop\Steel 1.SLDPRT Dec 4 08:17:11 2025

Weight:4.28938 N


Mirror2[1] | Solid Body | Mass:0.615448 kg Volume:7.8401e-05 m^3 Density:7,850 kg/m^3 Weight:6.03139 N | C:\Users\HP\Desktop\Steel 1.SLDPRT Dec 4 08:17:11 2025


Cut-Extrude3[1] | Solid Body | Mass:17.1355 kg Volume:0.00218286 m^3 Density:7,850 kg/m^3 Weight:167.928 N | C:\Users\HP\Desktop\Steel 1.SLDPRT Dec 4 08:17:11 2025


Trim/Extend1[2] | Solid Body | Mass:8.65652 kg Volume:0.00110274 m^3 Density:7,850 kg/m^3 Weight:84.8339 N | C:\Users\HP\Desktop\Steel 1.SLDPRT Dec 4 08:17:11 2025
Boss-Extrude2 | Solid Body | Mass:0.441309 kg Volume:5.62177e-05 m^3 Density:7,850 kg/m^3 Weight:4.32482 N | C:\Users\HP\Desktop\Steel 1.SLDPRT Dec 4 08:17:11 2025


Boss-Extrude4 | Solid Body | Mass:0.437691 kg Volume:5.57569e-05 m^3 Density:7,850 kg/m^3 Weight:4.28938 N | C:\Users\HP\Desktop\Steel 1.SLDPRT Dec 4 08:17:11 2025


Gusset1 | Solid Body | Mass:0.615448 kg Volume:7.8401e-05 m^3 Density:7,850 kg/m^3 Weight:6.03139 N | C:\Users\HP\Desktop\Stee l 1.SLDPRT Dec 4 08:17:11 2025

## Study Properties

Study name | Static 1
Analysis type | Static
Mesh type | Mixed Mesh
Thermal Effect: | On
Thermal option | Include temperature loads
Zero strain temperature | 298 Kelvin
Include fluid pressure effects from SOLIDWORKS Flow Simulation | Off
Solver type | Automatic
Inplane Effect: | Off
Soft Spring: | Off
Inertial Relief: | Off
Incompatible bonding options | Automatic
Large displacement | Off
Compute free body forces | On
Friction | Off
Use Adaptive Method: | Off
Result folder | SOLIDWORKS document (C:\Users\HP\Desktop)

## Units

Unit system: | SI (MKS)
Length/Displacement | mm
Temperature | Kelvin
Angular velocity | Rad/sec
Pressure/Stress | N/m^2

## Material Properties

Model Reference | Properties | Components
| Name: ASTM A992 Model type: Linear Elastic Isotropic Default failure criterion: Max von Mises Stress
| Yield strength: 3.45e+08 N/m^2 Tensile strength: 4e+08 N/m^2 Elastic modulus: 2e+11 N/m^2 Poisson's ratio: 0.26 Mass density: 7,850 kg/m^3 Shear modulus: 7.93e+10 N/m^2

SolidBody 1(Base-Flange2)(Steel 1-2),
SolidBody 2(Cut-Extrude2[1])(Steel 1-2),
SolidBody 3(Boss-Extrude6)(Steel 1-2),
SolidBody 4(Boss-Extrude1)(Steel 1-2),
SolidBody
5(Trim/Extend1[1])(Steel 1-2),
SolidBody 6(Boss-Extrude3)(Steel 1-2),
SolidBody 7(Boss-Extrude5)(Steel 1-2),
SolidBody 8(Base-Flange4)(Steel 1-2),
SolidBody 9(Cut-Extrude2[2])(Steel 1-2),
SolidBody
10(Mirror2[1])(Steel 1-2), SolidBody 11(Cut-Extrude3[1])(Steel 1-2),
SolidBody
12(Trim/Extend1[2])(Steel 1-2),
SolidBody 13(Boss-Extrude2)(Steel 1-2),
SolidBody 14(Boss-Extrude4)(Steel 1-2),
SolidBody 15(Cut-Extrude3[2])(Steel 1-2),
SolidBody 16(Gusset1)(Steel 1-2)


Curve Data:N/A

## Loads and Fixtures

Fixture name | Fixture Image | Fixture Details

Fixed-1

Entities: 2 face(s)
Type: Fixed
Geometry

Resultant Forces


Components | X | Y | Z | Resultant
Reaction force(N) | -0.00118256 | 20,155.7 | 0.000442505 | 20,155.7
Reaction Moment(N.m) | 0 | 0 | 0 | 1e-33
Load name | Load Image | Load Details


Force-1 | | Entities: 2 face(s) Type: Apply normal force Value: 10,000 N


Gravity-1

Reference: Top Plane
Values: 0 0 -9.81
Units: m/s^2

## Connector Definitions

No Data

## Interaction Information

Interaction | Interaction Image | Interaction Properties


Local Interaction-1 | | Type: Contact interaction pair Entities: 15 face(s) Advanced: Surface to surface
Local Interaction-2 | | Type: Contact interaction pair Entities: 15 face(s) Advanced: Surface to surface
Global Interaction | | Type: Bonded Components: 1 component(s) Options: Independent mesh

## Mesh information

Mesh type | Mixed Mesh
Mesher Used: | Blended curvature-based mesh
Jacobian points for High quality mesh | 16 Points
Jacobian check for shell | On
Maximum element size | 30.8238 mm
Minimum element size | 1.54119 mm
Mesh Quality | High
Remesh failed parts independently | Off
Reuse mesh for identical parts in an assembly (Blended curvature-based mesher only) | Off

### Mesh information - Details

Total Nodes | 682215
Total Elements | 374164
Time to complete mesh(hh;mm;ss): | 00:00:39

Computer name:

### Mesh Quality Plots

Name | Type | Min | Max
Quality1 | Mesh | - | -


steel-Static 1-Quality-Quality1

## Sensor Details

No Data

## Resultant Forces

### Reaction forces

Selection set | Units | Sum X | Sum Y | Sum Z | Resultant
Entire Model | N | -0.00118256 | 20,155.7 | 0.000442505 | 20,155.7

### Reaction Moments

Selection set | Units | Sum X | Sum Y | Sum Z | Resultant
Entire Model | N.m | 0 | 0 | 0 | 1e-33

### Free body forces

Selection set | Units | Sum X | Sum Y | Sum Z | Resultant
Entire Model | N | 0.0162354 | 383.786 | -0.0570679 | 383.786

### Free body moments

Selection set | Units | Sum X | Sum Y | Sum Z | Resultant
Entire Model | N.m | 0.0189691 | -0.059974 | -0.0746169 | 0.097593

## Beams

### No Data

## Study Results

Name | Type | Min | Max
Stress1 | VON: von Mises Stress | 2.556e+02N/m^2 Node: 342727 | 4.635e+08N/m^2 Node: 157400


steel-Static 1-Stress-Stress1

Name | Type | Min | Max
Displacement1 | URES: Resultant Displacement | 0.000e+00mm Node: 5125 | 1.310e+07mm Node: 681714


steel-Static 1-Displacement-Displacement1

Name | Type | Min | Max
Strain1 | ESTRN: Equivalent Strain | 1.347e-09 Element: 187698 | 1.526e-03 Element: 367439

steel-Static 1-Strain-Strain1

## Conclusion

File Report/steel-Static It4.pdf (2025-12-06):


Analyzed with SOLIDWORKS Simulation | Simulation of steel | 1

# Simulation of steel

Date: 01 December 2025
Designer: Solidworks
Study name: Static 5
Analysis type: Static

## Table of Contents

## Description

No Data

## Assumptions


Original Model | Model Analyzed

## Model Information


Model name: steel
Current Configuration: Default

### Solid Bodies

Document Name and Reference | Treated As | Volumetric Properties | Document Path/Date Modified
Mirror2[1] | Solid Body | Mass:0.615448 kg Volume:7.8401e-05 m^3 Density:7,850 kg/m^3 Weight:6.03139 N | C:\Users\HP\Desktop\CAD _Files\Steel 1.SLDPRT Dec 1 21:09:54 2025


Cut-Extrude3[1] | Solid Body | Mass:17.1355 kg Volume:0.00218286 m^3 Density:7,850 kg/m^3 Weight:167.928 N | C:\Users\HP\Desktop\CAD _Files\Steel 1.SLDPRT Dec 1 21:09:54 2025


Fillet Bead15 | Solid Body | Mass:0.0286001 kg Volume:3.64333e-06 m^3 Density:7,850 kg/m^3 Weight:0.280281 N | C:\Users\HP\Desktop\CAD _Files\Steel 1.SLDPRT Dec 1 21:09:54 2025


Fillet13 | Solid Body | Mass:9.9117 kg Volume:0.00126264 m^3 Density:7,850 kg/m^3 Weight:97.1347 N | C:\Users\HP\Desktop\CAD _Files\Steel 1.SLDPRT Dec 1 21:09:54 2025


Fillet Bead16 | Solid Body | Mass:0.0231394 kg Volume:2.94769e-06 m^3 Density:7,850 kg/m^3 Weight:0.226766 N | C:\Users\HP\Desktop\CAD _Files\Steel 1.SLDPRT Dec 1 21:09:54 2025

Gusset1 | Solid Body | Mass:0.615448 kg Volume:7.8401e-05 m^3 Density:7,850 kg/m^3 Weight:6.03139 N | C:\Users\HP\Desktop\CAD _Files\Steel 1.SLDPRT Dec 1 21:09:54 2025


Fillet Bead10 | Solid Body | Mass:0.0286001 kg Volume:3.64333e-06 m^3 Density:7,850 kg/m^3 Weight:0.280281 N | C:\Users\HP\Desktop\CAD _Files\Steel 1.SLDPRT Dec 1 21:09:54 2025


Fillet18 | Solid Body | Mass:9.90897 kg Volume:0.00126229 m^3 Density:7,850 kg/m^3 Weight:97.1079 N | C:\Users\HP\Desktop\CAD _Files\Steel 1.SLDPRT Dec 1 21:09:54 2025


Cut-Extrude2[1] | Solid Body | Mass:17.1584 kg Volume:0.00218578 m^3 Density:7,850 kg/m^3 Weight:168.152 N | C:\Users\HP\Desktop\CAD _Files\Steel 1.SLDPRT Dec 1 21:09:54 2025

## Study Properties

Study name | Static 5
Analysis type | Static
Mesh type | Mixed Mesh
Thermal Effect: | On
Thermal option | Include temperature loads
Zero strain temperature | 298 Kelvin
Include fluid pressure effects from SOLIDWORKS Flow Simulation | Off
Solver type | Automatic
Inplane Effect: | Off
Soft Spring: | Off
Inertial Relief: | Off
Incompatible bonding options | Automatic
Large displacement | Off
Compute free body forces | On
Friction | Off
Use Adaptive Method: | Off
Result folder | SOLIDWORKS document (C:\Users\HP\Desktop\CAD_Files)

## Units

Unit system: | SI (MKS)
Length/Displacement | mm
Temperature | Kelvin
Angular velocity | Rad/sec
Pressure/Stress | N/m^2

## Material Properties

Model Reference | Properties | Components
| Name: ASTM A992 Model type: Linear Elastic Isotropic Default failure criterion: Max von Mises Stress
| Yield strength: 3.45e+08 N/m^2 Tensile strength: 4e+08 N/m^2 Elastic modulus: 2e+11 N/m^2 Poisson's ratio: 0.26 Mass density: 7,850 kg/m^3 Shear modulus: 7.93e+10 N/m^2

SolidBody 1(Base-Flange11)(Steel 1-2),
SolidBody 2(Mirror2[1])(Steel 1-2),
SolidBody 3(Cut-Extrude3[1])(Steel 1-2),
SolidBody 4(Fillet
Bead15)(Steel 1-2),
SolidBody 5(Fillet13)(Steel 1-2),
SolidBody 6(Base-Flange12)(Steel 1-2),
SolidBody 7(Fillet
Bead16)(Steel 1-2),
SolidBody 8(Base-Flange13)(Steel 1-2),
SolidBody 9(Gusset1)(Steel 1-2),
SolidBody 10(Base-Flange9)(Steel 1-2),
SolidBody 11(Base-Flange7)(Steel 1-2),
SolidBody 12(Base-Flange8)(Steel 1-2),
SolidBody 13(Base-Flange14)(Steel 1-2),
SolidBody 14(Base-Flange10)(Steel 1-2),
SolidBody 15(Fillet
Bead10)(Steel 1-2),
SolidBody 16(Fillet18)(Steel 1-2),
SolidBody 17(Base-Flange2)(Steel 1-2),
SolidBody 18(Cut-Extrude2[1])(Steel 1-2),
SolidBody 19(Base-Flange4)(Steel 1-2)


Curve Data:N/A

## Loads and Fixtures

Fixture name | Fixture Image | Fixture Details

Fixed-1

Entities: 2 face(s)
Type: Fixed
Geometry

Resultant Forces


Components | X | Y | Z | Resultant
Reaction force(N) | 0.0203209 | 20,168.2 | 0.0890427 | 20,168.2
Reaction Moment(N.m) | 0 | 0 | 0 | 1e-33
Load name | Load Image | Load Details


Gravity-1

Reference: Top Plane
Values: 0 0 -9.81
Units: m/s^2


Force-1

Entities: 2 face(s)
Type: Apply
normal
force
Value: 10,000 N

## Connector Definitions

No Data

## Interaction Information

Interaction | Interaction Image | Interaction Properties


Global Interaction | | Type: Bonded Components: 1 component(s) Options: Independent mesh

## Mesh information

Mesh type | Mixed Mesh
Mesher Used: | Blended curvature-based mesh
Jacobian points for High quality mesh | 16 Points
Jacobian check for shell | On
Maximum element size | 30.5934 mm
Minimum element size | 1.52967 mm
Mesh Quality | High
Remesh failed parts independently | Off
Reuse mesh for identical parts in an assembly (Blended curvature-based mesher only) | Off

### Mesh information - Details

Total Nodes | 699218
Total Elements | 384721
Time to complete mesh(hh;mm;ss): | 00:01:48

Computer name:

### Mesh Quality Plots

Name | Type | Min | Max
Quality1 | Mesh | - | -


steel-Static 5-Quality-Quality1

## Sensor Details

No Data

## Resultant Forces

### Reaction forces

Selection set | Units | Sum X | Sum Y | Sum Z | Resultant
Entire Model | N | 0.0203209 | 20,168.2 | 0.0890427 | 20,168.2

### Reaction Moments

Selection set | Units | Sum X | Sum Y | Sum Z | Resultant
Entire Model | N.m | 0 | 0 | 0 | 1e-33

### Free body forces

Selection set | Units | Sum X | Sum Y | Sum Z | Resultant
Entire Model | N | 7.69982 | 407.242 | 24.4177 | 408.047

### Free body moments

Selection set | Units | Sum X | Sum Y | Sum Z | Resultant
Entire Model | N.m | -4.17283 | -3.33536 | 3.07341 | 6.16303

## Beams

### No Data

## Study Results

Name | Type | Min | Max
Stress1 | VON: von Mises Stress | 1.628e-02N/mm^2 (MPa) Node: 129910 | 3.532e+02N/mm^2 (MPa) Node: 538302


steel-Static 5-Stress-Stress1

Name | Type | Min | Max
Displacement1 | URES: Resultant Displacement | 0.000e+00mm Node: 1765 | 5.077e+00mm Node: 352473


steel-Static 5-Displacement-Displacement1

Name | Type | Min | Max
Strain1 | ESTRN: Equivalent Strain | 1.709e-07 Element: 22233 | 1.113e-03 Element: 273445

steel-Static 5-Strain-Strain1


Image-1

Image-2

## Conclusion

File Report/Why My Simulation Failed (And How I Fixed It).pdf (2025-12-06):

# Why My Simulation Failed (And How I Fixed It)


Optimizing a Steel Warehouse using Six Sigma & FEA

FAIL: 475 MPa | PASS: 353 MPa

# The Failure


The Problem: Internal
stiffeners disconnected
from the column web during simulation.
Root Cause: Default 'Beam
Elements' (1D lines) could not form bonded contact
sets with the 3D faces of the plates.
Result: Infinite displacement (10km error).

# The Theory Check: Hand Calc vs. FEA

Validating the Simulation with Beam Theory


My manual beam calculation predicted a nominal stress of 106 MPa. The FEA simulation revealed a peak stress of 317 MPa.

The ratio approx 3.0 matches the theoretical Stress Concentration Factor (Kt) for a sharp corner, validating that the simulation is capturing the correct geometric physics.

# The Theory Check: Hand Calc vs. FEA

Validating the Simulation with Beam Theory

Inference:
The FEA result 5.12 mm is higher than the theoretical fixed beam 3.24 mm but significantly lower than a pinned beam

### 16.2 mm. This indicates that:

Column Flexibility: The hand calculation assumes the supports are "infinitely rigid walls." In reality, the steel columns possess elasticity and bow slightly outward under load, allowing the roof to sag further than a perfectly fixed beam.

Structural Behavior: The result confirms that the frame is functioning as a Semi-Rigid to Rigid structure, successfully resisting the majority of the bending rotation at the corners.


Comparison & Inference
Theoretical (Perfectly Fixed): 3.24 mm FEA Result (Actual Frame): 5.12 mm

# The Optimization (The Fix)


Fillet Added
(Simulating Weld)

Stress Reduced
to 317 MPa

Engineering a Safer Design

Geometric Refinement: Introduced fillet radii at connection points to simulate weld beads, eliminating the sharp-corner stress singularity.

Mesh Strategy: Converted beams to Solid Elements to enable accurate face-to-face bonding with stiffeners.

Material Upgrade: Switched to ASTM A992 Steel (Sy = 345 MPa) to align with modern structural standards.

Parameter | Hand Calc / Theory | FEA Result | Conclusion
Total Reaction Force | 20,167 N | 20,167 N | ✅ Equilibrium
Max Stress | 106 MPa (Nominal) | 353 MPa (Peak) | ✅ Matches Kt
Max Deflection | 3.246 mm | 5.12 mm | ✅ Safe (Span/500)

# Final Validation & Equilibrium Check

Static Equilibrium: ΣFy = 0 is satisfied. The ground reaction matches the applied load perfectly.
Stiffness: Max deflection is only 5.12 mm, confirming the frame is rigid and behaving elastically.
Stability: Buckling Load Factor (BLF) = 5.05, meaning the structure can handle 5x the load before collapsing.

# Structural Stability Analysis

to instability."

Ensuring the Columns Won't Collapse

The Test: Performed a Linear
Buckling Analysis to ensure
the tall columns won't fail due

The Result: Buckling Load
Factor (BLF) = 5.0498.

Conclusion: The structure
theoretically requires 5x the
applied load (50 kN) to
buckle. Since we are only
applying 10 kN, the design is
Extremely Stable.

Anything > 3.0 is considered safe in industry.
A BLF of 5.05 means your columns are extremely

strong and stable.

# The Conclusion

### The Takeaways

It’s not just about CAD: This project taught me that simulation tools are useless without a deep understanding of Structural Mechanics and Material Behavior.

The Six Sigma Approach: By applying the DMAIC methodology, I turned a failing model (475 MPa) into a safe, optimized design (353 MPa).

Ready for Industry: I have verified the results against theory, ensuring the design is feasible, efficient, and safe. What’s Next? Part 3: MATLAB Verification"(Building a custom Matrix Stiffness Solver to prove the math)
Karthik V S Mechanical Engineering Undergraduate, Open to Summer 2026 Internships in Design & FEA

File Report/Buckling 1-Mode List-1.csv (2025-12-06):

11:49 | Saturday | December 06 | 2025
Study name:Buckling 1
Mode No. | Buckling Factor of Safety
1 | 5.0498
Buckling Load |  | 50.5 KN

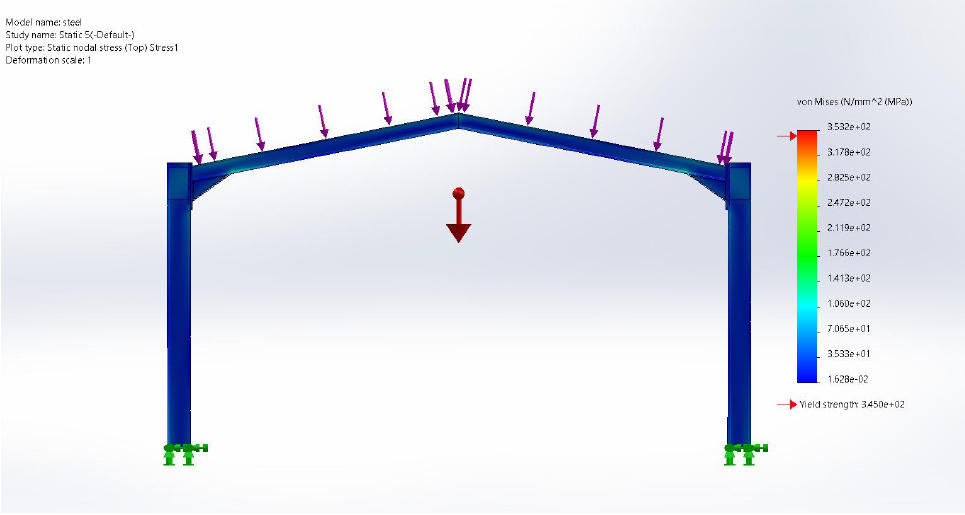
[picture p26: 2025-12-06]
Assets/Screenshot 2025-12-01 225107.png

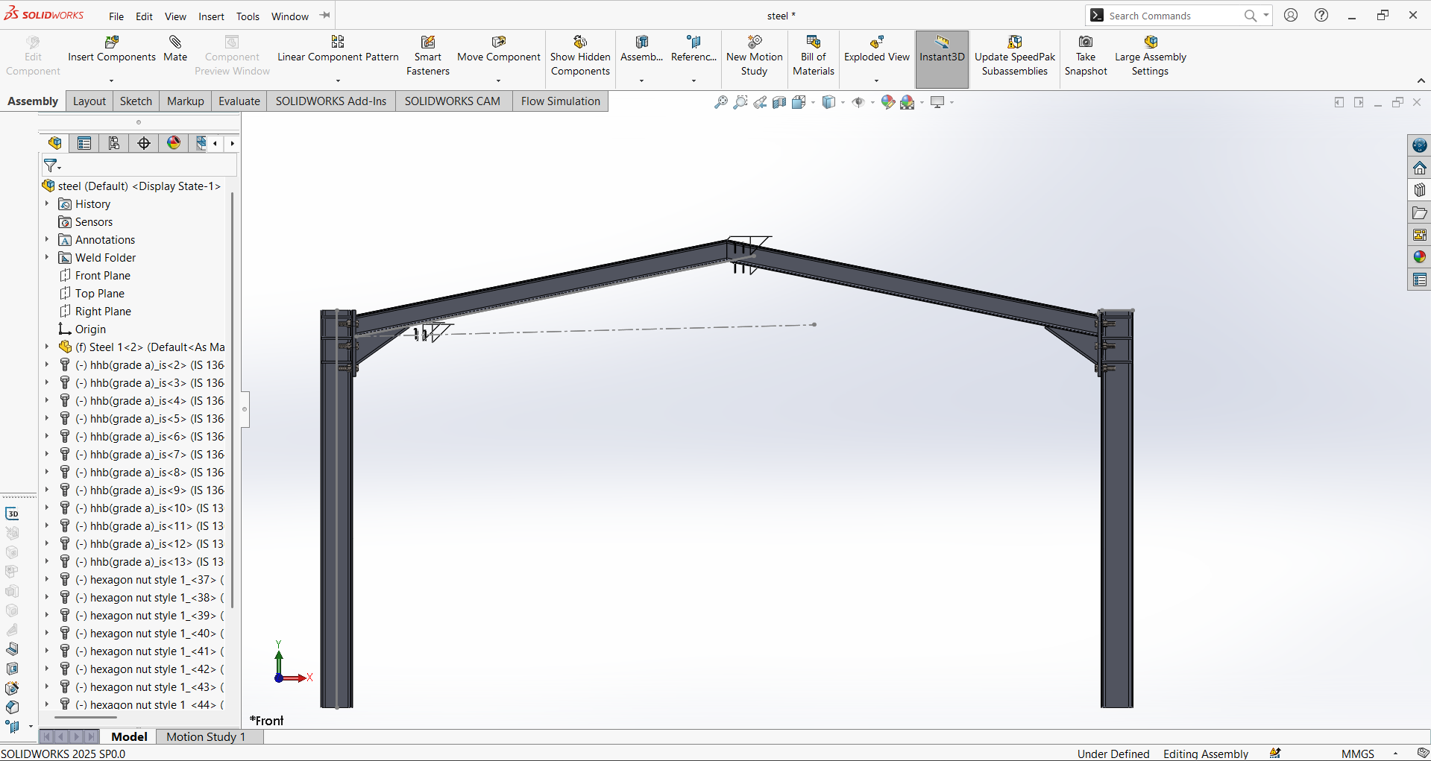
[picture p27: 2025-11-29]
Assets/Screenshot 2025-11-29 070829.png

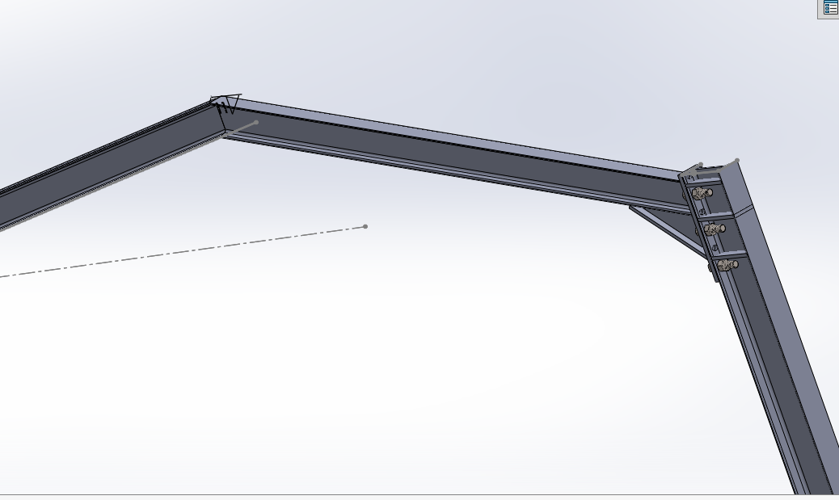
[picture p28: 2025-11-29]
Assets/Screenshot 2025-11-29 070935.png

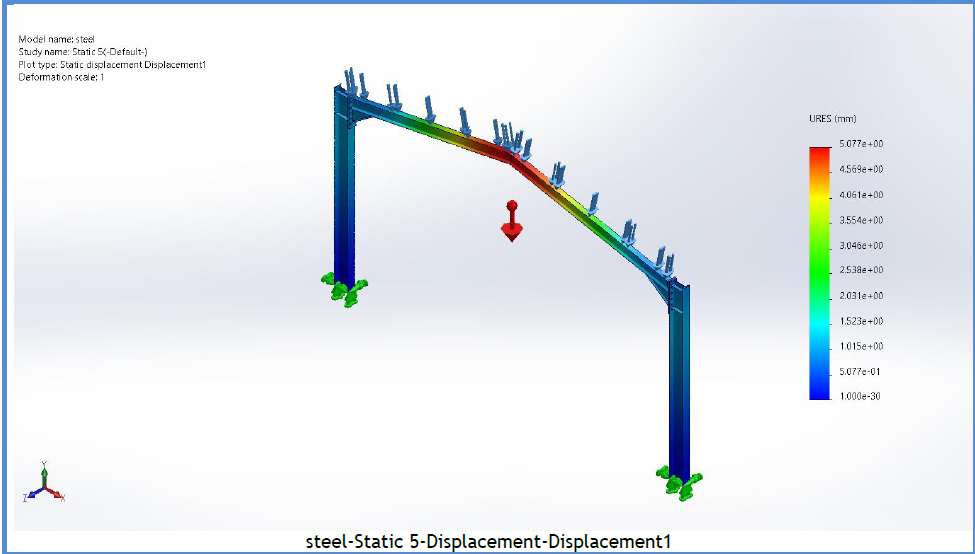
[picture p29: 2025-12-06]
Assets/Screenshot 2025-12-01 225130.png

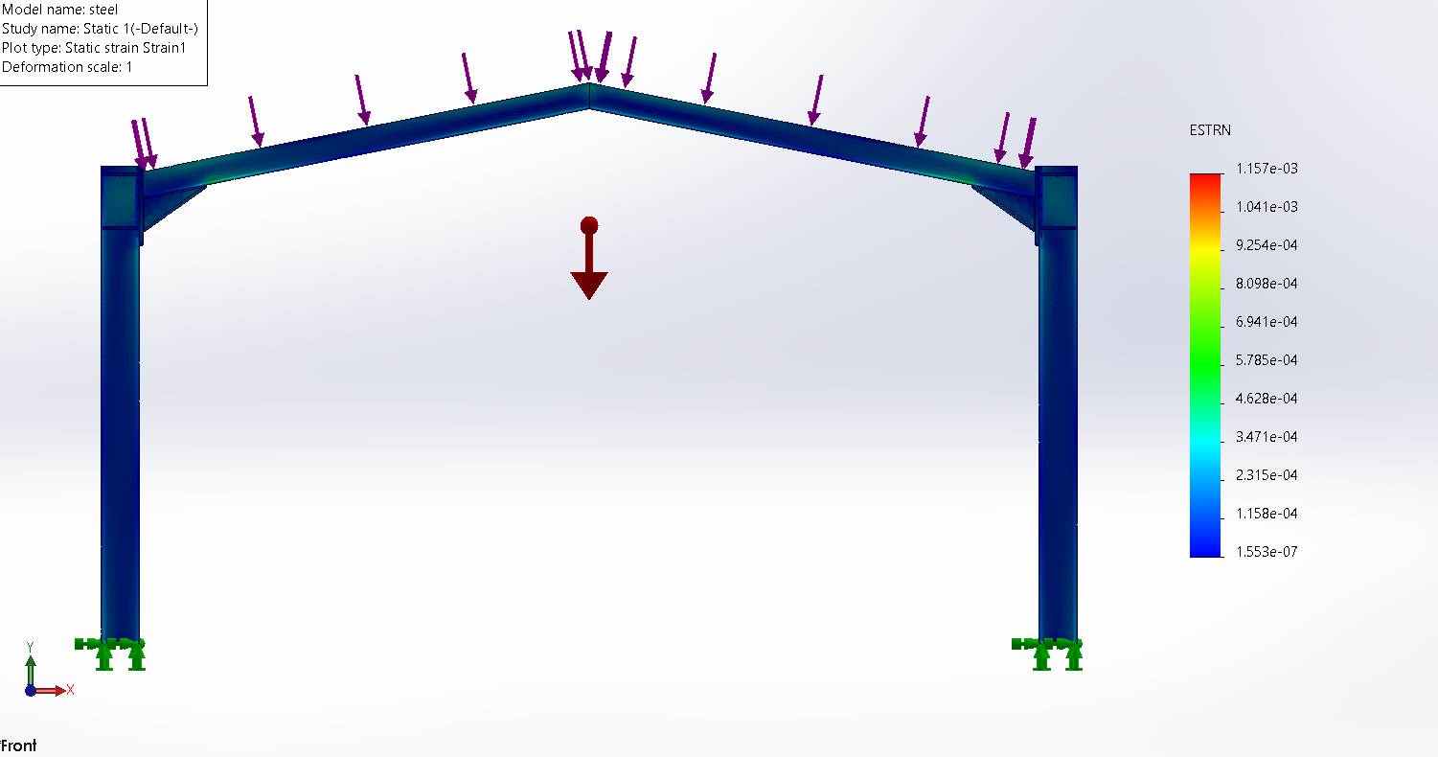
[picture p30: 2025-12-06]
Assets/Screenshot 2025-12-05 180937.png

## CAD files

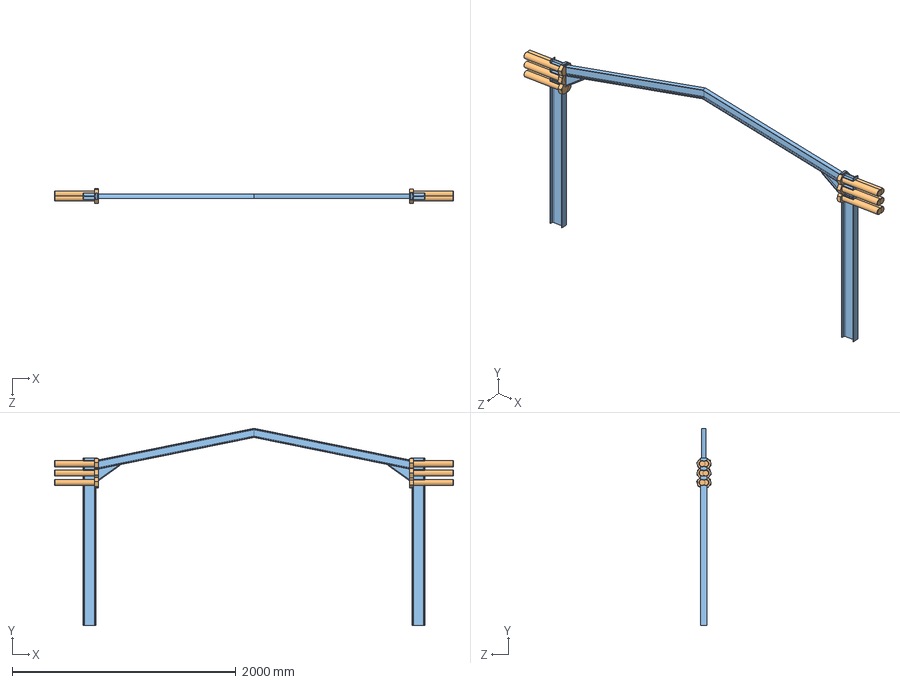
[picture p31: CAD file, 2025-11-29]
CAD_Files/steel.SLDASM
3570.0 x 1765.6 x 132.4 mm
Steel 1
hhb(grade a)_is x 12
hexagon nut style 1_ x 12

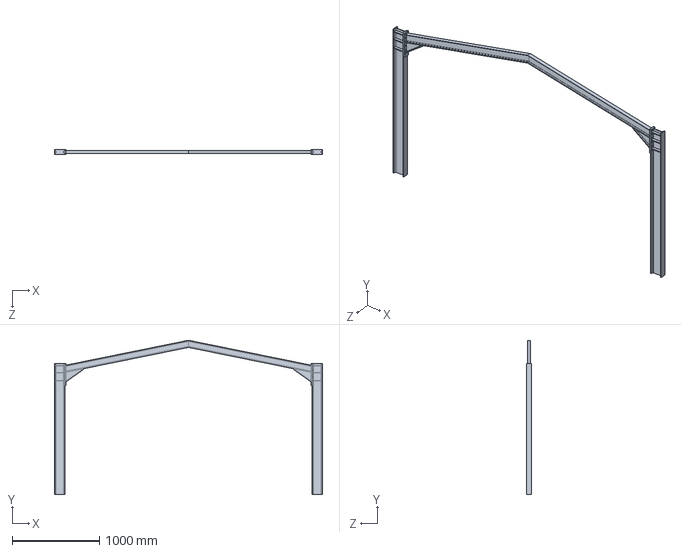
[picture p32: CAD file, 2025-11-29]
CAD_Files/Steel 1.SLDPRT
3064.0 x 1765.6 x 60.0 mm

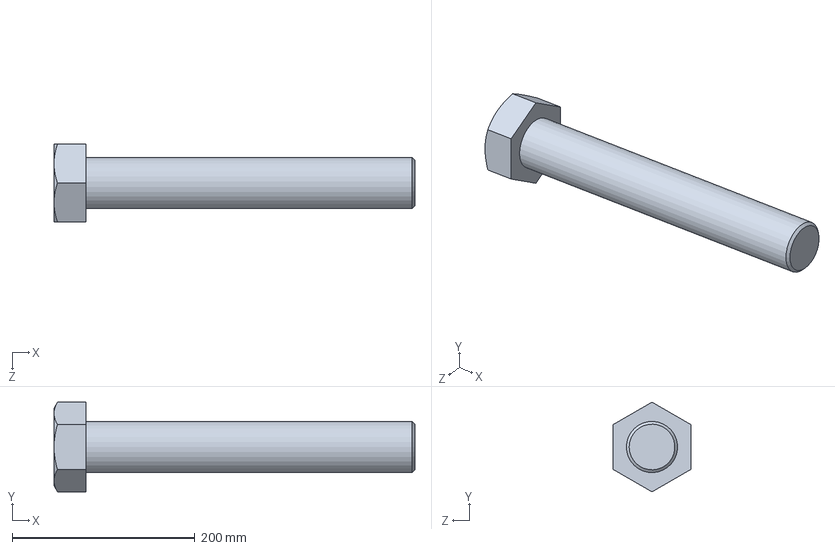
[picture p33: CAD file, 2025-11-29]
CAD_Files/hhb(grade a)_is.sldprt
395.0 x 98.1 x 85.0 mm

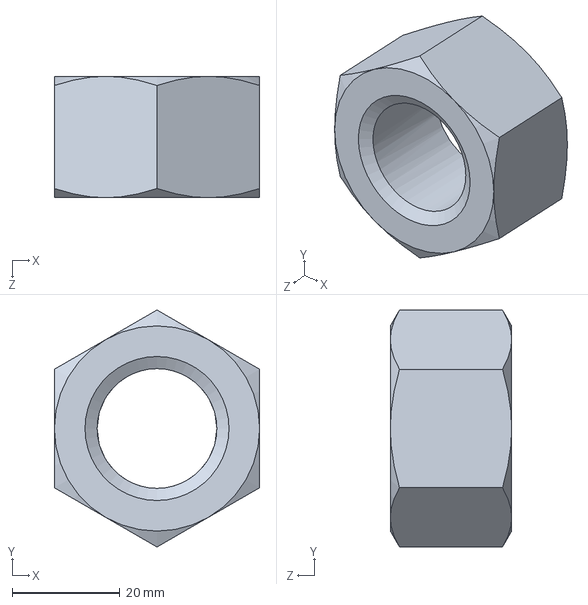
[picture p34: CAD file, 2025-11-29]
CAD_Files/hexagon nut style 1_.SLDPRT
38.1 x 44.0 x 22.5 mm

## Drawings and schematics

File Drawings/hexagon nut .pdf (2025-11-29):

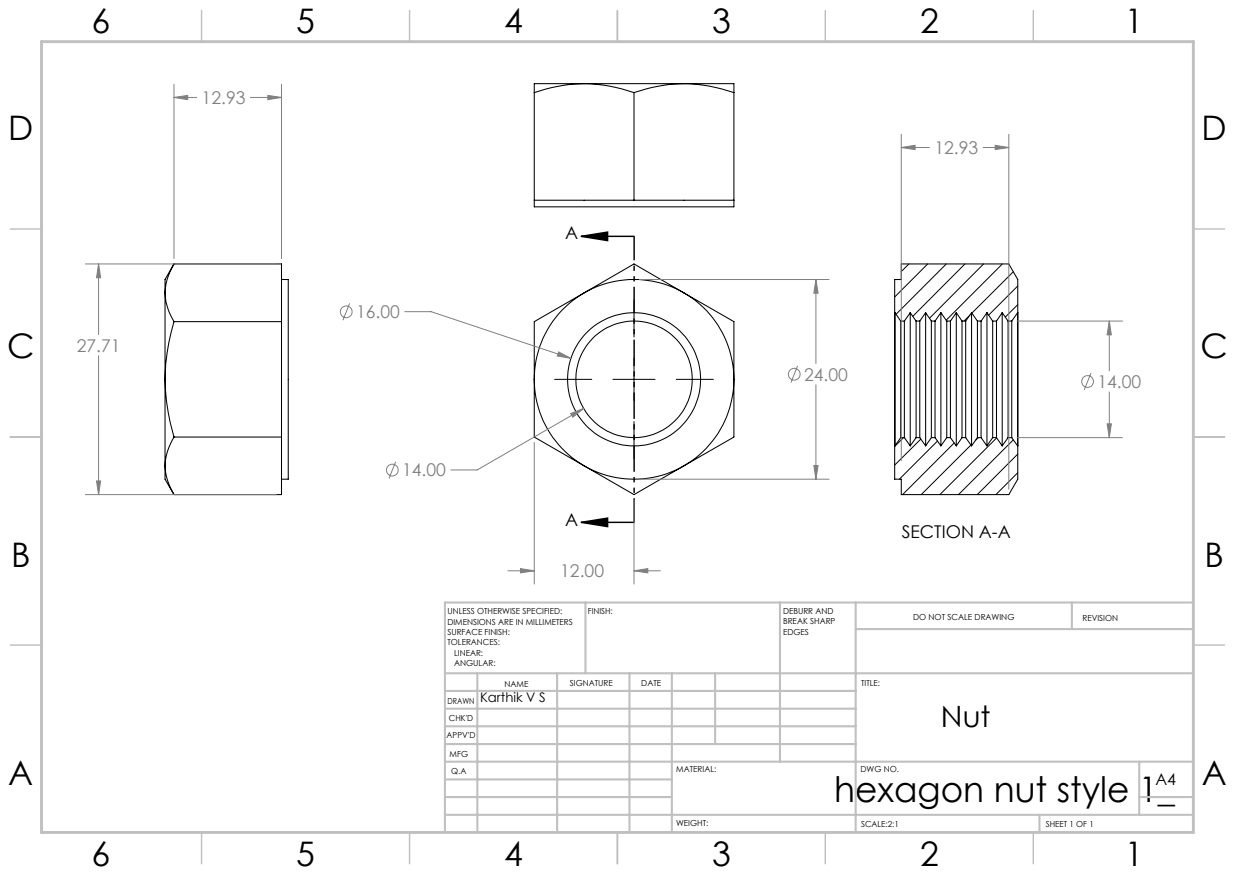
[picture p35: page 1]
SECTION A-A; FINISH:; DEBURR AND; BREAK SHARP; DO NOT SCALE DRAWING; REVISION; SCALE:2:1; SHEET 1 OF 1

UNLESS OTHERWISE SPECIFIED:
DIMENSIONS ARE IN MILLIMETERS
SURFACE FINISH:
TOLERANCES:
LINEAR:
ANGULAR:

NAME | SIGNATURE | DATE | | | | TITLE: Nut

DRAWN | Karthik V S

CHK'D
APPV'D
MFG
Q.A | | | | MATERIAL: hexagon nut style 1_ | DWG NO. | A4

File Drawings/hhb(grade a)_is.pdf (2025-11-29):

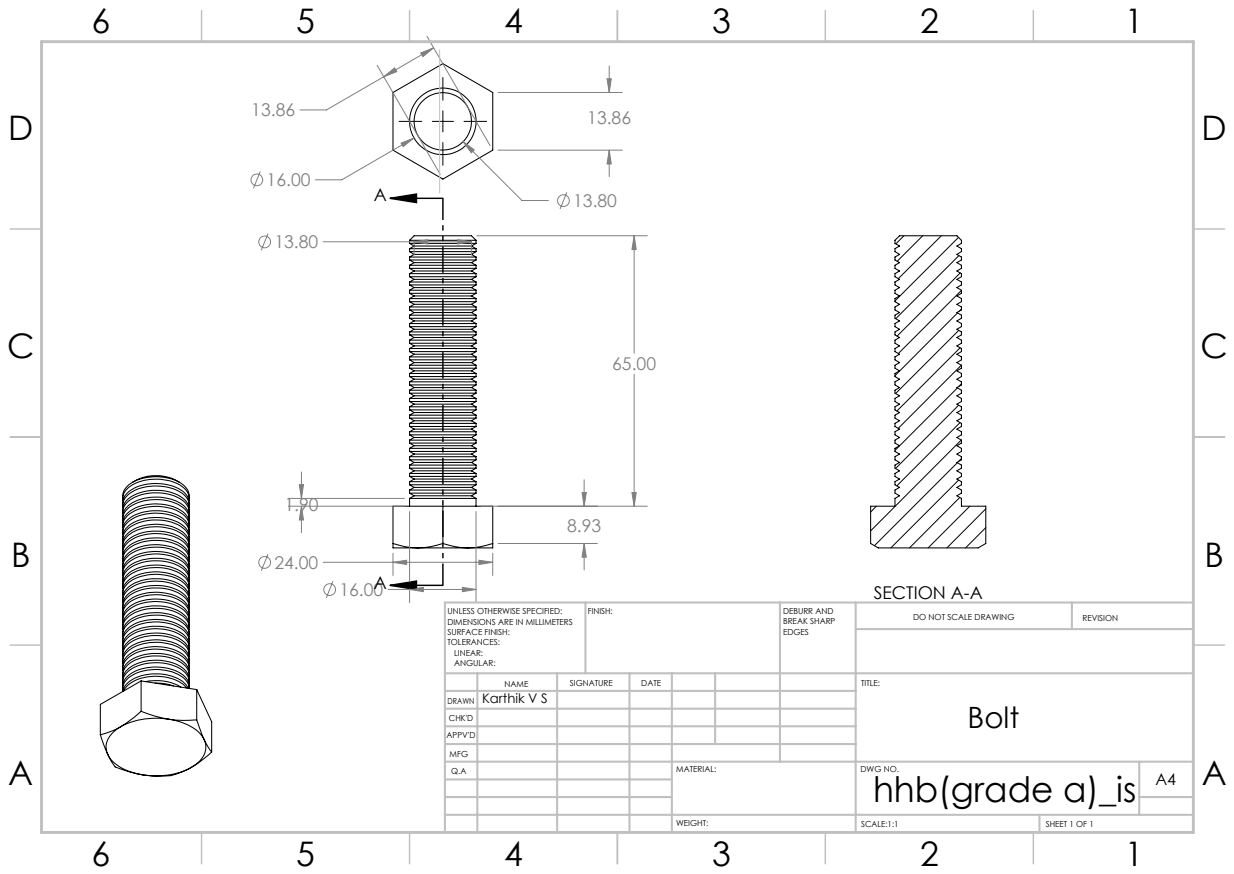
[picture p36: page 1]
SECTION A-A; FINISH:; DEBURR AND; BREAK SHARP; DO NOT SCALE DRAWING; REVISION; SCALE:1:1; SHEET 1 OF 1

UNLESS OTHERWISE SPECIFIED:
DIMENSIONS ARE IN MILLIMETERS
SURFACE FINISH:
TOLERANCES:
LINEAR:
ANGULAR:

NAME | SIGNATURE | DATE | | | | TITLE: Bolt

DRAWN | Karthik V S

CHK'D
APPV'D
MFG
Q.A | | | | MATERIAL: | DWG NO. hhb(grade a)_is | A4

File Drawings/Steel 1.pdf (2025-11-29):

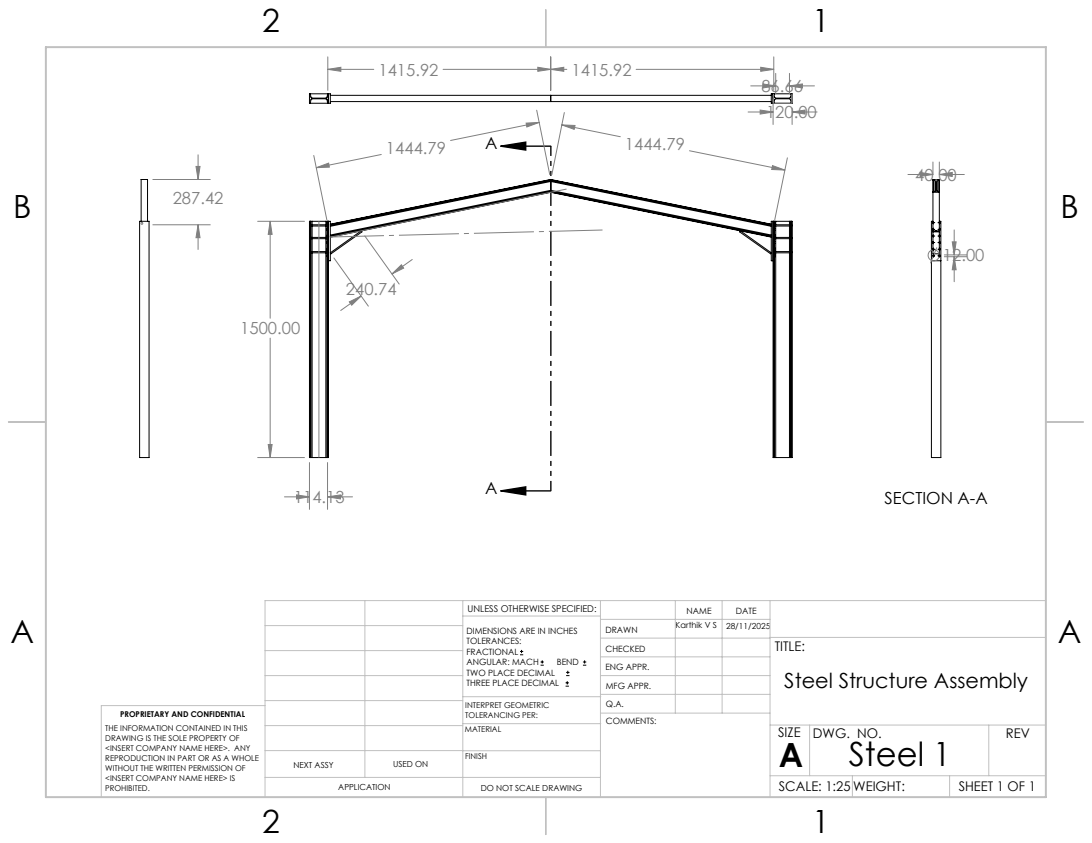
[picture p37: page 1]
SECTION A-A

UNLESS OTHERWISE SPECIFIED: | | NAME | DATE
DIMENSIONS ARE IN INCHES TOLERANCES: FRACTIONAL ANGULAR: MACH BEND TWO PLACE DECIMAL THREE PLACE DECIMAL | DRAWN | Karthik V S | 28/11/2025

CHECKED | | | TITLE: Steel Structure Assembly

ENG APPR.
MFG APPR.

INTERPRET GEOMETRIC TOLERANCING PER: | Q.A.
MATERIAL | | SIZE A | DWG. NO. Steel 1 | REV

PROPRIETARY AND CONFIDENTIAL
THE INFORMATION CONTAINED IN THIS
DRAWING IS THE SOLE PROPERTY OF
<INSERT COMPANY NAME HERE>. ANY
REPRODUCTION IN PART OR AS A WHOLE
WITHOUT THE WRITTEN PERMISSION OF
<INSERT COMPANY NAME HERE> IS
PROHIBITED.

NEXT ASSY | USED ON | FINISH

APPLICATION | DO NOT SCALE DRAWING | | SCALE: 1:25 WEIGHT: | | SHEET 1 OF 1

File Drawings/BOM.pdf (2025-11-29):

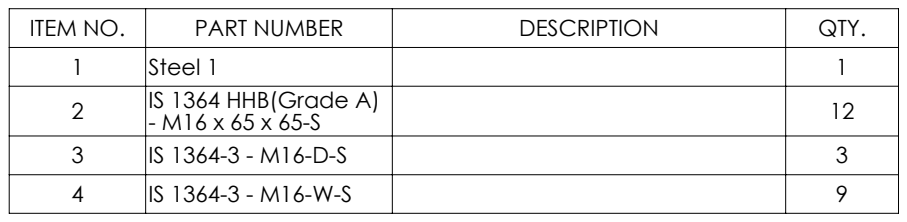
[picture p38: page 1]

ITEM NO. | PART NUMBER | DESCRIPTION | QTY.
1 | Steel 1 | | 1
2 | IS 1364 HHB(Grade A) - M16 x 65 x 65-S | | 12
3 | IS 1364-3 - M16-D-S | | 3
4 | IS 1364-3 - M16-W-S | | 9

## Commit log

2025-11-29 Rename Screenshot 2025-11-29 070811.png to Assembly
2025-11-29 Change project banner image to 'Assets/Assembly'
    Updated project banner image path in README.
